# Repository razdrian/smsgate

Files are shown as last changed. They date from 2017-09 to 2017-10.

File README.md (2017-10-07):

* Project Name: SMSGate 
* Descrtiption: Bridge between LAN and GSM using d-uGSM module (based on Quectel UG95) and Raspberry Pi 3
* Date: 2016-11-22 
* Author: Adrian-Razvan Petre 
* [Under AMIQ Education Program](http://www.amiq.com/consulting/education/)

## Application structure: ##
* The main app has three main flows : SMS, FS (file system) and POP(e-mail service).
* The main app will decide how to treat a command coming from a flow and redirect it to another flow.
* In the first implementation, the one described in the blog article an Ethternet connection was needed
* In the last implementeation available here as last version the internet connection comes from a PPP connetion from GPRS via the d-uGSM module

## Directory structure: ##
* smsgate/documents -> 
	* smsgate/documents/c-uGSM_module/  -> GSM docs, official http://itbrainpower.net/ sketch examples and the initial API provided by DragosIosub
	* smsgate/documents/documentation -> SMSGate User's Guide and Article (both docx and pdf files) 
	
* smsgate/sources -> executable code files for the SMSGate application 
	* smsgate/sources/ppp -> PPP start and stop scripts
	* smsgate/sources/py -> Python application source code
		* smsgate/sources/py/lib -> Library files and definition of some methods from GSM_modem class
		* smsgate/sources/py/src -> Python source files
		* smsgate/sources/py/test -> uitest cases for some basic features of the implemented classes
		* smsgate/sources/py/tmp -> scratchpad for python code snippets
	* smsgate/sources/sh -> scrips used in the work in progress stage

* smsgate/schematic -> cadence Capture and Allegro schematic design and documents (complete BOM and pdf schematics)
 	* smsgate/schematic/commandModule_v1_3 -> commandModule is the LEDs and RR push button Printed Circuit Board.
		* smsgate/schematic/commandModule_v1_3/allegro -> Cadence allegro files (brd files)
		* smsgate/schematic/commandModule_v1_3/documents -> commandModule BOM and pdf schematic
		* smsgate/schematic/commandModule_v1_3/gerberFiles -> production gerberFiles and drl file 
	* smsgate/schematic/datasheets -> pdf datasheet files for all the components in the desgn 
	* smsgate/schematic/powerModule_v1_3 ->  the main module of this system including the d-uGSM module and voltage regulators for both the 5V and 4V voltages required by the system. In the PCB version available here (v1_3) I2C connectors are externalized from the IDC10 connector to a CON2 for later use. This is also valid for the unused pins of the d-uSGM module (e.g. RI - ring indicator)
		* smsgate/schematic/powerModule_v1_3/allegro -> Cadence allegro files (brd files)
		* smsgate/schematic/powerModule_v1_3/documents -> powerModule BOM and pdf schematic
		* smsgate/schematic/powerModule_v1_3/gerberFiles -> production gerberFiles and drl file 

* smsgate/var_smsgate -> direcotry whose content must be copied in /var/smsgate at the first initialization of the SMSGate application on a brand new Rasbian OS. If this content is not copied in the /var/smsgate the python application will crash and give an error message. The template.eml and template.sms are two tempalte files for a new sms and email command. If this type of files are pasted in the input directory (/var/smsgate/input) the SMSGate daemon will parse them immediately and delete them after execution.

## Raspbian configuraton: ##
* Install Raspbian and mount its image
* Disable Raspberry Serial Console
* sudo raspi-config -> 8. Advanced Options -> A8. Serial -> Disable 
* Enable UART
* sudo vim /boot/config.txt and update enable_uart=0 to enable_uart=1 
* sudo apt-get install python3.
* edit $HOME/.bashrc and add export PYTHONPATH=$PYTHONPATH:$HOME/smsgate/src/py/lib:$HOME/smsgate/src/py/src

## Documentation links
* [itbrainpower original GSM project](http://itbrainpower.net/micro-GSM-shield-module-cuGSM/GSM-micro-shield-board-module-RaspberryPI-Arduino-c-uGSM-features-code-examples)
* [release UART interface at RPi3](https://learn.adafruit.com/adafruit-nfc-rfid-on-raspberry-pi/freeing-uart-on-the-pi)
* [Logging in python](https://docs.python.org/3/library/logging.html#levels)
* [About IMAP and SMTP](https://automatetheboringstuff.com/chapter16/)
* [Unitest in python](https://docs.python.org/2/library/unittest.html)
* [unix daemon in Python](http://web.archive.org/web/20131025230048/http://www.jejik.com/articles/2007/02/a_simple_unix_linux_daemon_in_python/)

## Fusion 360 system Housing 
* [view/download the design in Web Browser here](https://myhub.autodesk360.com/ue2906e76/g/shares/SHabee1QT1a327cf2b7a7fcac2ec095da1a6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)

## Acknowledgements
* Dragos  Iosub from ITBrainPower provided a library sketch  with the d-uGSM Module. The communication with the module in the SMSGate application is based on this API, which was a very good starting point.

## Amiq Consulting blog article
* [here](https://www.amiq.com/consulting/2017/03/24/mentoring-young-talent-through-hands-on-applications/)

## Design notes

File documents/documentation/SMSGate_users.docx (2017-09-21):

# SMSGate User’s Guide

# 1. Overview

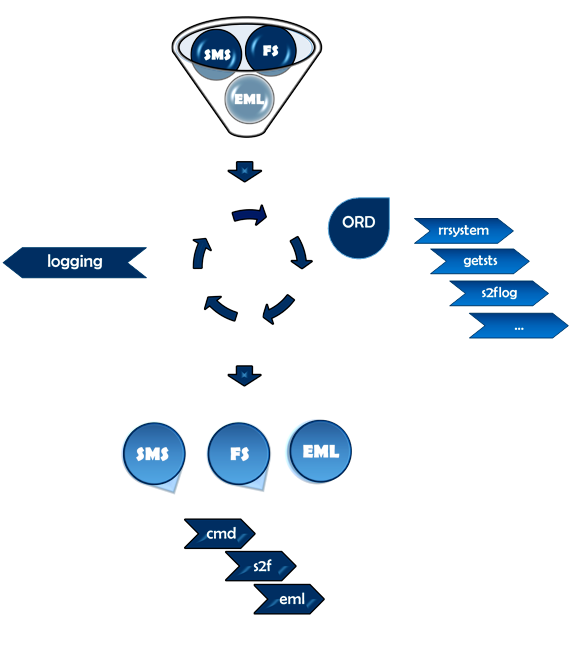
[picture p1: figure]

SMSGate is a bridge between LAN and the GSM network. It can be used by system administrators to monitor and control one or more computers on the LAN. What is by far its most important feature is the ability of handling files and scripts via the Raspberry PI file system, becoming a framework for future development. Its main core can be controlled via ‘commands’ to run user written scripts or executable files located in a specified path. The user can also get information about the system via ‘orders’.

Figure 1 – SMSGate system flow diagram

The SMSGate application has the following features:

- Receive an SMS and send it via email to one or more recipients
- Receive an email and send it via SMS to one or more recipients
- Receive a command file through the file system and execute one or more commands
- Feature a phone book of employees and groups
- Be power failure safe and run even when the power is down
- Be “light” and cheap, easy to use and start up
- Implemented using Python
- Allow for future software and hardware extensions
- On-board rechargeable battery and charging circuit
- Real-time battery level monitor
- Real-time notification about important events: battery level low, Ethernet down (notification via SMS) or SMS down (notification via Ethernet)

The input data is received from three sources: GSM connection, Email and File System. An event received from one of the sources will determine an output on one of the other two data sources. All activity is logged in a text file for later review by the admin.

# 1. Hardware system description

The whole system is built around a Raspberry Pi 2 running a Raspbian Lite OS. The single-board computer is powered by a +5V voltage source from the Power module. Inside the Power module there are two voltage regulators providing the +5V and the +4V voltage needed for the GSM module (Quectel M95).

When the power line of +12V in down (i.e. unlike situation of a power loss) the switching logic implemented with two Schottky diodes will move almost instantaneous the input of the voltage regulators from the +12V input to the 8.4V LiPol battery providing the system with power failure immunity. The SMSGate can have an up time of up to 6 hours on battery.

The current drain from and to the battery is counted by the Coulomb counter, a small integrated circuit which gives the system an INT signal every time an amount of 0.34 mA has passed from the battery to the rest of the system or vice versa. The direction of this flow is given by the state of the POL pin, i.e. ‘a low state of POL indicates the current flowing out of the battery while high impedance means the current is going into the battery’ [1].

The Battery charger block manages charging of the 8.4V LiPol battery. The charging in progress is signaled on the front panel of the SMSGate by an orange led. The presence of power is signaled by a green led.

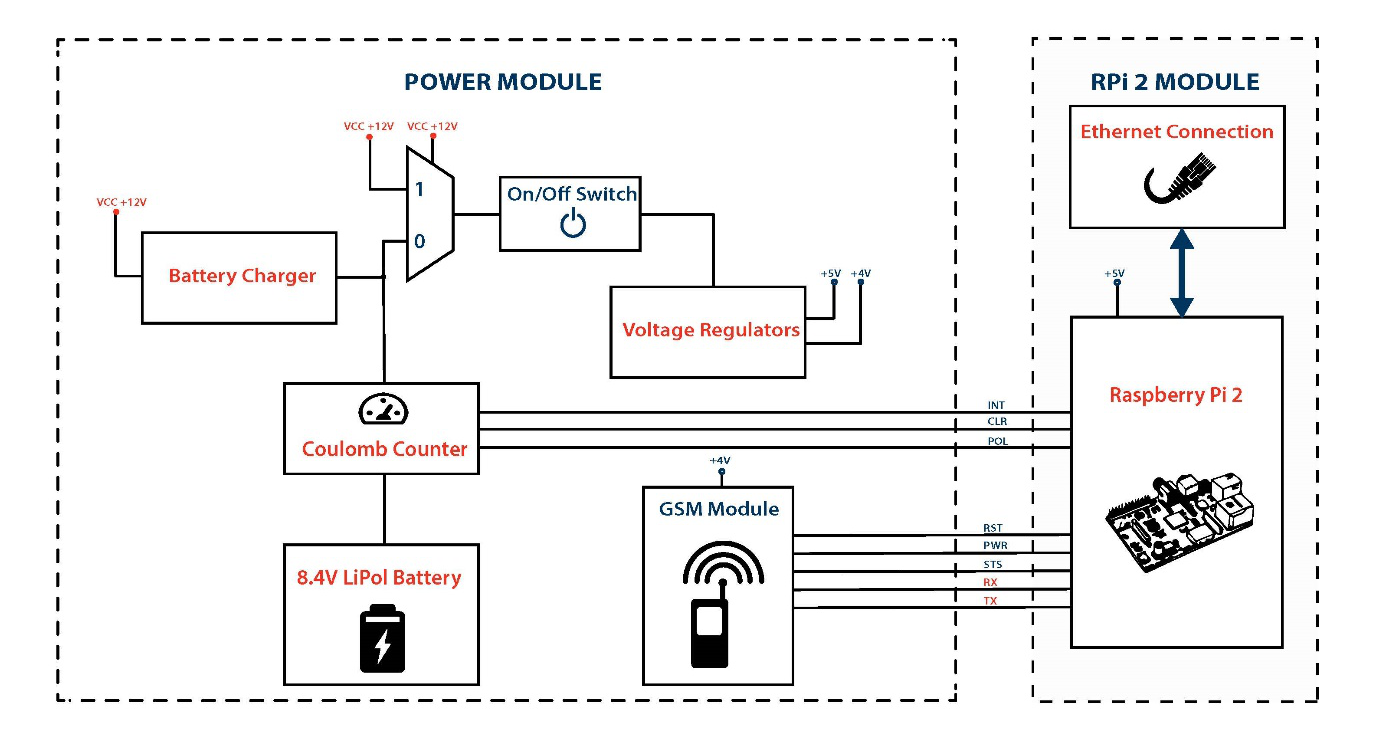
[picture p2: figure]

Figure 2 – Block diagram of the SMSGate system

# 2. Software description

## 3.1 General flow

The table above describes the channel switching flow for the smsgate system. A red X means that the switch is not permitted and a green tick means it is available.

The actions, keywords which must be included at the beginning of each sms/email, are in blue color. An ‘ord’ action must be preceded by another keyword defining the specific order, words written in gray in the table. You can read more about how the action and content should be split in the 5. Use Cases section.

Action Flow | sms | eml | S2f | cmd | ord
| | | | | rrsys | rrdmn | getsts | getlog | st2sts | s2flog
SMS
Email
FS

* you will get a short status of your smsgate system via the sms/email to the same number/email address of the sender

** only from/to authorized members (from the phonebook)

## 3.2 Sequence diagram

This section briefly describes how the smsgate processes data through one of the main three flows.

First of all, the whole application is written in python and developed as a daemon running in the background of the Raspbian system. The regular sudo service start|stop|restart|status commands are supported by the daemon. The sudo service smsgate status command will print the current status of the service in terminal. If the user desires to get information about the smsgate system (threads status, GSM signal level etc.), he should enter the statusgsm command in the console and the result will be outputted in the txt file /var/smsgate/livestatus.txt.

The application is organized in 3 threads, one for each data flow. The worker associated with the thread checks if a new file/command has arrived and handles it. Before a new polling is made, a certain amount of time in seconds elapses as a delay. This delay can be configured in the globalPara.py file. Every thread sets up a flag while in idle mode (i.e. while the delay time elapses), this being the only moment when it can be killed. This is implemented to prevent a thread to be killed while reading data from UART of retrieving an email from IMAP which could raise errors.

Sending the sudo service smsgate stop terminal command for the Raspbian OS will generate a wait state while the system waits for each thread to set the up his own kill flag. Only when this flag is set, the smsgate system shuts down the corresponding thread. However, if more than the usual delays[‘<flow>’] +deltaTimeOut elapses and the kill flag is not set up, the thread will be killed immediately. After killing the three threads the systemQuit method is called, which shuts down the Quectel M95 and quits from the IMAP and SMTP connections.

Almost every method implemented for this application return a logical True value if it has accomplished its task or False if not. The possible error for a method is handled by the callee method in almost every situation. The only error considered not resolvable by retry is the lack of communication with the QuectelM95. If more than ATcmdNOFRetry times in a row the QM95 does not send response to a command via UART the whole system will shut down to indicate a serious hardware issue..

Figure 3 - Threads sequence diagram

Figure 4 – Email handling method

Figure 5 – SMS handling method

Figure 6 – File System handling method

## 3.3 File system

The *.py source code files are stored in the directories /home/pi/sources/py/sources and /home/pi/soruces/py/lib. In the lib directory it is located the global parameters file (globalPara.py) where the admin can modify some system parameter later presented in the section 3.4 Global Parameters.

Another important directory for the use of this system is /var/smsgate/, which is created by the administrator while setting up the application for the first time. More about this in section 4.1 Clone GitHub repository. The /var/smsgate contains the following:

- phonebook.json -> json file which includes all the contacts and groups of contacts relevant for the application. This is referred as the agenda of the system.
- livestatus.txt -> text file where the system outputs its status after a ‘sudo service smsgate statusgsm’ command. It is called live because the old status is always removed from the file.
- batCap.txt -> text file used by the system to store the battery capacity. There is no need for the user to read this file since the battery capacity information is included in the statusgsm.
- tempalte.sms and template.eml -> template text files for a new email and sms. The user can copy them in the /var/smsgate/input directory and make a first test (after changing the phone number/email in the txt file).
- input directory -> files inserted here will be handled immediately by the system and they should followthe template described in the 5. Use cases section.
- output directory -> this directory has 3 subdirectories: savedlogs, savedsts and savedtxt. Each of this subdirectory is used to save the current day log (when the ‘ord#s2flog’ order is received), the current moment of time gsm status (when the ‘ord#s2fstsl’ order is received) or a simple txt file when the action ‘#s2f#fileTitle#body here’ is received
- logging directory -> contains the logging.txt log file
- commands directory -> all the executable scripts that can be executed by a cmd action. This folder is is mandatory because the system only searches this directory for commands.

## 3.4 Global parameters

The global parameters are stored in the globalPara.py file in /home/pi/smsgate/src/py/lib/ directory and constitute a control dashboard of the application. The administrator must modify these parameters to control the smsgate. There are several categories of parameters:

- General parameters -> general parameters for the system such as the UART speed or hardware connection pins for the Quectel M95 or the coulomb counter.
- Username and passwords -> Username and password for the email connection. To access another email account via IMAP (retrieving email) and SMTP (sending email) the administrator must change the login address and password. The email key is defined as a string mandatory at the end of the subject for a received email. More about this in the 5. Use cases section.
- Restrictions specifications -> The system is designed to verify if the user provides the right parameters to an action. An email address is considered valid only if its domain is among the ‘allowed_domains’ and if its username does not contain special_EMLchars. For the output file name in the s2f action, the system verifies if it does not contain special_FSchars. Finally, a phone number is considered valid only if it has exactly 10 digits in local format (e.g. 0724000000).
- Global variables -> In this section the admin can modify global variables for the system. The most important is the ‘delays’ dictionary, which contains the delay time between two iterations in the sms thread, email or fs thread. Another important parameter which should be mentioned is the ATcmdNOFRetry, which is the number or retries the system does if no response is received for a command sent to QuectelM95 before quitting. The other parameters are clearly explained by their suggestive name. More about the behavior of the system according to these parameters in the 3.1 General flow section.
- Program Paths -> String parameters are defined here to locate the resources for the system. Even if it is not recommended, these paths can be changed, the admins having this option in the global parameters file.
- Logging -> The logging format can be customized here (e.g. date format, message format)

## 3.5 Phonebook

The phonebook whose path is indicated by the phonebook_path (global parameter) contains a list of the known people. For each person there are some mandatory attributes. These are ID, Name, Email and PhoneNo. The sysadmin must modify these parameters to fit his needs. A theoretically unlimited amount of registrations can be introduced here. The phonebook file is organized as a json file and adding a new registration must obey the default template. If an employee has no email or phone number, the field must be completed with an empty string.

There are also groups defined in this json file and membership to a specified group is defined by adding the employee ID in the respective group list. Note that the employee ID is introduced as an integer in this area. Groups are adding a powerful feature to smsgate, that of sending a notification to a whole predefined group rather than to a list of people. The group alias (e.g. admins) should be remembered by the user because will be used to define the attribute of a future action.

The json file is parsed and inserted into the system only once when the smsgate starts or restarts. If a change is made in the json file, the daemon must be restarted for this change to take effect.

{

"employees": [

{

"ID": "1",

"Name": "Ives Tamboon",

"PhoneNo": "0724000000",

"Email": "ives.tamboon@gmail.com"

},

{

"ID": "2",

"Name": "Leila Dopoller",

"PhoneNo": "0724000000",

"Email": "leila.dopoller@gmail.com"

},

{

"ID": "3",

"Name": "Helga Gosond",

"PhoneNo": "0724000000",

"Email": "helga.gosond@gmail.com"

},

{

"ID": "4",

"Name": "Emory Spesper",

"PhoneNo": "0724000000",

"Email": "emory.spesper@gmail.com"

},

{

"ID": "5",

"Name": "Bertha Loltent",

"PhoneNo": "0724000000",

"Email": "bertha.loltent@gmail.com"

}

],

"groups": {

"admins": [

1,

2

],

"sysadmins": [

1,

2,

3

],

"staff": [

1,

5,

3

]

}

}
| Figure 2 – phonebook.json example file

# 3. Install and setup

## 4.1 Clone GitHub repository

First, if not installed already, you need to install Git on Raspbian:

sudo apt-get install git

Then clone the GitHub repository on your Raspbian system:

git clone https://github.com/razdrian/smsgate.git

Now create a new folder called smsgate in /var/ and copy into it the entire contents of the /var_smsgate folder from the repository you just cloned. If /var/smsgate/input, /var/smsgate/output/savedsts, /var/smsgate/output/savedlogs and /var/smsgate/output/savedtxt directories are not created make sure to create on your own or otherwise the application will now work properly.

!!!!! Application should be installed using a dedicated unix user/group. It must not necessarily be root user. !!!!!

## 4.2 How to start smsgate service

Move the smsgate file???which file??? from the repository to /etc/init.d. This file contains the application which runs as a service in Raspbian. Create a symbolic link called K02smsgate in directories /etc/rc0.d /etc/rc1.d and /etc/rc6.d by typing the following command each time in the corresponding directory:

sudo ln -s /etc/init.d/smsgate K02smsgate

Create a symbolic link called S01smsgate in directories /etc/rc2.d /etc/rc3.d, /etc/rc4.d and /etc/rc5.d by typing the following command each time in the corresponding directory:

sudo ln -s /etc/init.d/smsgate S01smsgate

Now the smsgate application will run as a service in Raspbian and you can also send it commands such as start, stop, restart, status or statusgsm. A detailed status of the system will be outputted to /var/smsgate/livestatus.txt file every time you type:

sudo service smsgate statusgsm

From this time on, the smsgate application will run as a daemon and will start every time the Raspberry Pi starts and will shut down every time the Raspberry Pi shuts down.

## 4.3 Service commands

The smsgate service supports the basic commands of any other linux daemon such as start|stop|restart|status. Moreover, a statusgsm command is available to get the smsgate system status in the /var/smsgate/livestatus.txt file since the regular status command will only give you the linux daemon status (up and running, up time etc).

# 4. Use cases

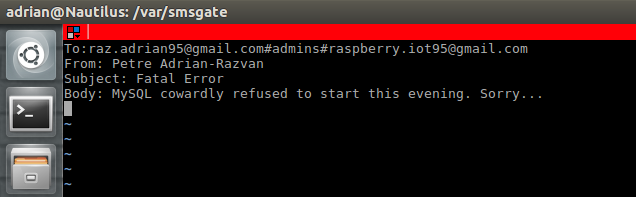
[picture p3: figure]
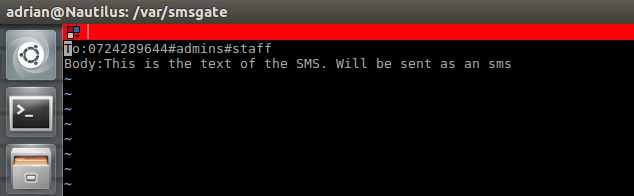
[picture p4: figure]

- FS to Email FROM: Any RPi User with access to /var/smsgate/input/ directory TO: Only users from phonebook The file MUST be saved in input_path with the format <file>.email e.g. tempalte.email single recipient: template.email - To: raz.adrian95@gmail.com multiple recipients: - To: raz.adrian95@gmail.com, raspberry.iot95@gmail.com group recipients: - To: Admin#Staff - Subject: My SQL has stopped - Body: Today at around 9PM the mySQL server has stopped! | - FS to SMS FROM: Any RPi User with access to /var/smsgate/input directory TO: Only users from phonebook The file MUST be saved in input_path with the format <file>.sms e.g. template.sms template.sms single recipient: - To: 0724000000 multiple recipients: - To: 0724000000#0724000001 group recipients: - To: Users - Body: Today the apache server died but was resurrected!

- Email to SMS FROM: Any Email address, but only specified subject format TO: any valid Phone Number or Group e.g. single recipient: - Mail Subject: sms#0724000000#6FA32E multiple recipients: - Mail Subject: sms#0724000000#0724000001#6FA32E group recipients: - Mail Subject: #Admin#6FA32E - Mail Body: This is an SMS send from smsgate system! * (no more than 160 characters. or only the first 160 will be sent) | - Email to FS FROM: Any Email address, but only specified subject format TO: Raspberry Pi File System e.g. - Mail Subject: s2f#fileTitle#6FA32E - Mail Body: This is a text file located in the /var/smsgate/output/savedtxt directory
| - SMS to FS FROM: Only users form the phonebook TO: Raspberry Pi File System e.g. - SMS Body: s2f#sputnik#This text will be saved in the output path directory under the name sputnik.
- Email to cmd FROM: Any Email address, but only specified subject format TO: SMSGate core e.g. single command: - Mail Subject: cmd#blinkred.py#6FA32E - Body: void multiple command: - Mail Subject: cmd#blinkred.py#blinkyellow.py#6FA32E - Body: void | - SMS to command FROM: Only users form the phonebook TO: SMSGate core e.g. single command: - SMS Body: cmd#backup_sql.sh multiple commands: - SMS Body: cmd#backup_sql.sh#restart_server.sh

- Email to cmd FROM: Only users form the phonebook TO: any valid email address or group e.g. single recipient: - SMS Body: eml#raz.adrian95@gmail.com#Emmergency from Petre#I have no internet conn. Call me ASAP! multiple recipients: - SMS Body: eml#raz.adrian95@gmail.com#raspberry.iot95@gmail.com#Bad day#I have lost my toothbrush! group recipients: - SMS Body: eml#Admin#EMMERCENCY#The power is off!

# 5. References

[1] Terminator (https://gnometerminator.blogspot.ro/p/introduction.html) – useful tool for arranging terminals
[2] Pycharm Edu (https://www.jetbrains.com/pycharm-edu/) - free, easy and professional Python programming tool
[3] OrCAD Cadence Lite (http://www.orcad.com/buy/try-orcad-for-free) – OrCAD Capture CIS for schematic diagram design and PCB editor for Gerber files
[4] GerbTool (http://www.wssi.com/index.php?option=com_content&task=view&id=182&Itemid=183) by WISE Software, free trial download for inspecting Gerber files.
[5] Fusion 360 (http://www.autodesk.com/products/fusion-360/overview) AUTODESK – 3D CAD and CAE tool
[6] About Epydoc documentation (http://epydoc.sourceforge.net/epydoc.html)
[7] Free UART (https://learn.adafruit.com/adafruit-nfc-rfid-on-raspberry-pi/freeing-uart-on-the-pi) from RaspberryPi
[8] Logging in Python (https://docs.python.org/3/library/logging.html)
[9] About IMAP and SMTP
[10] Unitest in Python (https://docs.python.org/2/library/unittest.html)
[11] Unix daemon in Python (http://web.archive.org/web/20131025230048/http:/www.jejik.com/articles/2007/02/a_simple_unix_linux_daemon_in_python/)
[12] Python script running as Daemon (http://stackoverflow.com/questions/1603109/how-to-make-a-python-script-run-like-a-service-or-daemon-in-linux) in Linux
[13] Poplib (https://docs.python.org/3/library/poplib.html) in Python
[14] Parsing (http://stackoverflow.com/questions/17872094/python-how-to-parse-things-such-as-from-to-body-from-a-raw-email-source-w) a raw email
[15] Imaplib example (https://yuji.wordpress.com/2011/06/22/python-imaplib-imap-example-with-gmail/) using Gmail
[16] Threading in Python (https://pymotw.com/2/threading/)
[17] Getting a Python script to run in the background (http://blog.scphillips.com/posts/2013/07/getting-a-python-script-to-run-in-the-background-as-a-service-on-boot/)
[18] Disable Bluetooth (http://raspberrypi.stackexchange.com/questions/45570/how-do-i-make-serial-work-on-the-raspberry-pi3) to make serial work on RPi3
[19] Best Guide (https://www.digikey.com/en/articles/techzone/2016/sep/a-designer-guide-fast-lithium-ion-battery-charging) to Li-ion and LiPo battery charger
[20] How to make (https://www.instructables.com/id/How-to-make-PCB-at-Home/) your own PCBs at home

# 6. Licenses

The SMSGate application is Licensed under the Apache License, Version 2.0 (the “License”). You may not use this file except in compliance with the License. You may obtain a copy of the License (http://www.apache.org/licenses/LICENSE-2.0)

PyCharm Edu is free & open source. It is licensed under the Apache License, Version 2.0. It is specifically targeted at students and designed to help students learn to program in Python.

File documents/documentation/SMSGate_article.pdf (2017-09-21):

SMSGate

## How to Make an SMS-to-Network Gate

## Contents

## 1 Introduction

This article doesn’t have too much to do with functional verification, but keep reading and you’ll be amazed at what a 3rd year student can achieve with the right kind of guidance.
Razvan was one of our 2016 Verification Summer Course participants. My attention was drawn by his ability to grasp new complex concepts in no time at all, his attention to detail and his focus on getting things done. We met again sometime around the end of September 2016 and discussed starting a collaboration under the umbrella of the AMIQ Education Program. We first agreed on a real life problem to solve and a working methodology, then we rolled up our sleeves and got to work... well, it was mostly Razvan’s sleeves that got rolled up. “Learning-by-doing” is the name of the game.
We chose the SMSGate project for three reasons: it solves a real life problem, it covers a wide range of different subjects (from design to implementation, hardware to software, initial idea to final product), and it fits with a students’ expected level of knowledge and time constraints. An SMSGate is a bridge between a LAN and GSM network that can be used by system administrators to monitor and control one or more computers on the LAN.
The working methodology was designed to empower Razvan to take decisions and act on them, to allow me to support him in a fast, efficient way, and to maintain a constant work pace. We met regularly for 2-4 hours every 1.5 weeks, with the exception of weeks allocated to exam sessions. During these mentoring sessions we discussed technical issues, I sometimes helped him with a debug, and we explored the business side of the project. Last but not least, we discussed his career path, his available options, the possible choices and subjects to focus on at different stages, and other projects he was working on.
The project touched on the essential aspects of any real life project: it gave Razvan the opportunity to interact with future users, to understand their needs, and advocate for his solution. He learned how to integrate hardware and software components using new technologies, completing three iterations before arriving at a final version. He designed the PCB and the enclosing box and produced them using 3rd party vendors. As you can see, it was Razvan who did most of the work on this project, and its success is mostly thanks to him.
Why was it a success? Because it was up and running in less than 6 months despite the time (full time student) and knowledge constraints (Linux, Python), and because he designed, implemented and packaged the whole thing in the same way as would be required of a real life project.
Thank you Razvan for your collaboration. Keep up the good work, you have a great future ahead of you.
I will now pass over to Razvan, who will present his project.

## 2 Application Requirements

The SMSGate application has the following features/requirements:
- Receive an SMS and send it via email to one or more recipients
- Receive an email and send it via SMS to one or more recipients
- Receive a command file through the file system and execute one or more commands
- Feature a phone book of employees and groups
- Be power failure safe and run even when the power is down
- Be “light” and cheap, easy to use and start up
- Implemented using Python
- Allow for future software and hardware extensions
- On-board rechargeable battery and charging circuit
- Real-time battery level monitor
- Real-time notification about important events: battery level low, Ethernet down (notification via SMS) or SMS down (notification via Ethernet)

All application requirements were accomplished in the first version of the system and a couple more were added to provide a fully 24-hour operable application. In total there were three versions: v1.0 – the first prototype, v1.1 – in which a custom PCB was created, and v1.2 – the final version.

## 3 Hardware

3.1Bill of Materials (BOM)
Here is a list of all the main components you need for this application:
- Raspberry Pi 2 Model B (https://www.raspberrypi.org/products/raspberry-pi-3-model-b/) (Pi 3 and Pi 2 also acceptable)
- Micro shield GSM c-uGSM (https://www.robofun.ro/cu-gsm-ufl?search=gsm&sub_category=true)
- GSM Antenna connector SMA (https://www.robofun.ro/antena_gsm_gprs_quad_band?search=gsm&sub_category=true)
- uFL to SMA adapter (https://www.robofun.ro/cablu_rpsma_ufl?search=SMA&sub_category=true)
- Rechargeable 2200mAh (https://hobbyking.com/en_us/zippy-compact-2200mah-3s-25c-lipo-pack.html) battery
- 5V 2A high efficiency voltage regulator (http://www.tme.eu/en/details/amsr2-7805-nz/dcdc-converters/aimtec/) (2 pc.)
- Adjustable voltage regulator (http://www.tme.eu/en/details/mic29302wu/ldo-regulated-voltage-regulators/microchip-micrel/) (4V out)
- Li-ion and LiPo 8.4V/2A battery charger (http://ro.farnell.com/texas-instruments/bq2057wsn/ic-charge-manager-li-ion-soic/dp/1212263?ost=BQ2057WSN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)
- Coulomb counter to measure battery level (http://ro.farnell.com/linear-technology/ltc4150cms-pbf/batt-gas-gauge-coul-counter-10msop/dp/1648053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)
- Schottky rectifier diode, small voltage drop, high current (http://ro.farnell.com/nxp/pmeg4020er/diode-schottky-re-40v-2a-sod123w/dp/1829200)

- P-Channel MOSFET, high power dissipation (http://ro.farnell.com/vishay/si4463cdy-t1-ge3/mosfet-p-ch-w-d-20v-18-6a-so8/dp/2056686?ost=2056686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)
- AC/DC power supply (http://ro.farnell.com/xp-power/vec40us12/adaptor-ac-dc-12v-3-33a/dp/2524402?ost=2524402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)

Additionally, you will also need a couple of passive components, such as resistors and capacitors, and some suitable connectors between the Power Module, the Raspberry Pi and the Micro shield GSM. A complete BOM including these is provided in the GitHub repository. (https://github.com/razdrian/smsgate.git)

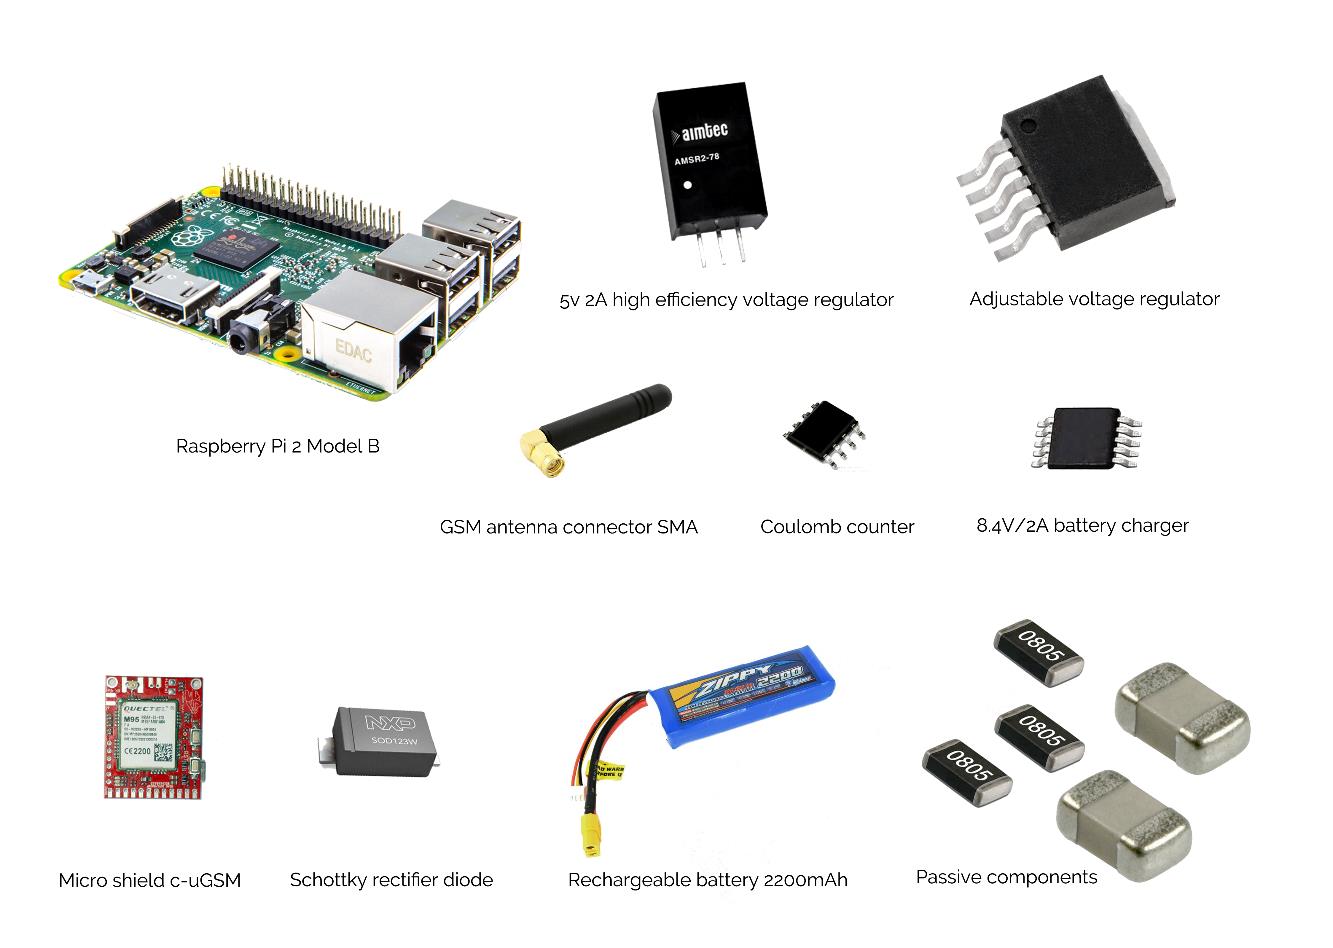
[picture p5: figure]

All these hardware components must be connected according to the system schematics, as described in the Schematics section. This project also requires a basic set of laboratory instruments, such as:
- Adjustable voltage source
- Breadboard and wires for initial prototype
- Soldering station for soldering components onto the Power Module
- Keyboard and display for Raspberry Pi

Figure 1 – All the hardware components needed to build the SMSGate system

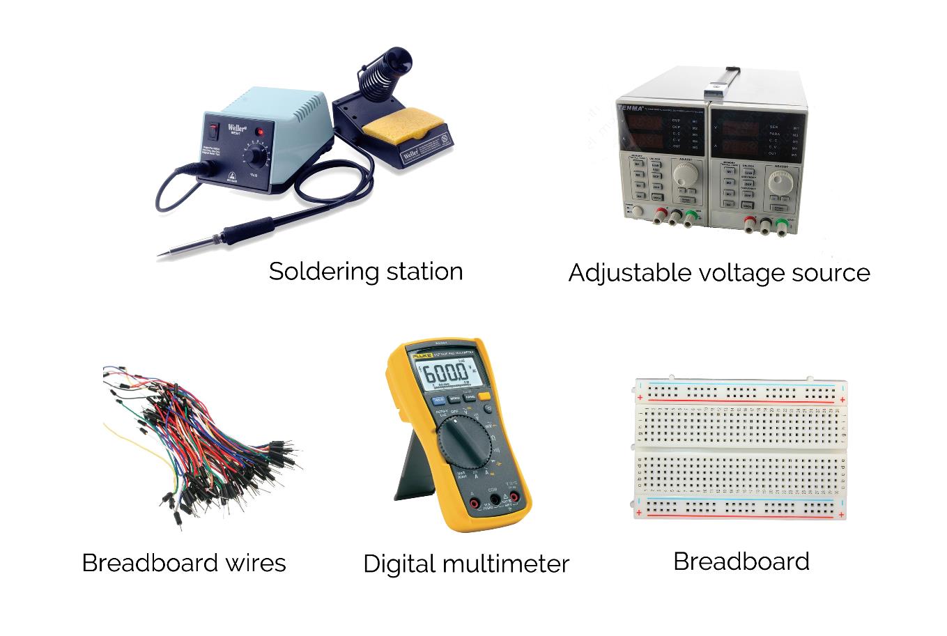
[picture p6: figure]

The Gerber files for the PCB connecting all the components are provided in the GitHub repository. (https://github.com/razdrian/smsgate.git) However, for this part of the project it is recommended to contact a factory specialized in PCB production, such as VI&RUS Factory. (http://vrint-pcb.com/show/11-Technology) Placing and soldering on the components can be done either manually at home and soldered using a soldering station, or in a pick-and-place environment and soldered in an oven. One laboratory that provides all these facilities is the CETTI (http://www.cetti.ro/v2/) at the Faculty of Electronics, Telecommunication and Technology of Information. (http://www.electronica.pub.ro/)

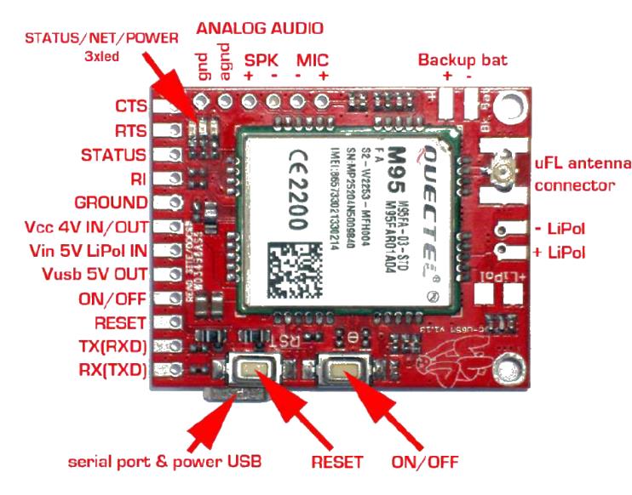
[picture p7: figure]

3.2Schematic Diagram
The schematics for this
project were designed to meet all the requirements and provide 24-hour functionality for the system. During development I created 3 versions of the system, v1.0, v1.1, and v1.2, each a slight improvement on the previous version.

Figure 2 – Basic laboratory instruments needed for the project

3.2.1 The RaspberryPi to GSM Module interface
The GSM module was designed by its producer to be a ‘shield’ for Arduino and Raspberry Pi. It has an integrated battery charger for a 3.7V Li-ion Battery that you can choose whether to connect or not. There are multiple ways of powering it up:
- +4V on Vcc 4V IN pin (between 3.6V and 4.2V is accepted) from a switching-mode power supply (recommended) without a LiPo battery
- +5V on Vin 5V LiPo IN with a 3.7V LiPo battery connected. The +5V is used to charge the battery that powers up the module
- USB connection for power with 3.7 LiPo battery connected
3.2.2 Powering up the system
For v1.2 (final version), I chose the first way of powering up the GSM module (external +4V power source) using a switching voltage regulator with a high efficiency (93%) to save as much battery power as possible. There is no 3.7V LiPo battery connected to a charging circuit and I designed a charging circuit for the 8.4V LiPo battery in the system.
3.2.3 Coulomb counter
In order to keep track of the battery level, I added to the schematic diagram a coulomb counter which sends the RPi an interrupt signal every time a fixed amount of current passes from the battery to the system or vice versa. The current flow direction is indicated via the POL signal. If the POL is logically ‘True’ then the battery is charging, and if it is logically ‘False’ it is discharging (i.e. current flowing from the battery to the SMSGate).
3.2.4 Charging circuit
The charging circuit was implemented using a BQS2057WSN IC, which charges the battery with a constant current of 200mAh. This value was chosen to be so small as to provide a long life for the battery and bearing in mind the use case for this back-up power supply: i.e. only in extreme situations when the power is down.
I chose the transistor which drives the battery current flow carefully after taking into account all possible limitations, such as power dissipation or voltage drops. One issue I was lucky to spot and able to resolve on time was that the thermistor employed as a temperature sensor required a 10uF capacitor to be used in parallel with it in order to prevent the following situation: when the battery is low and the power comes back from the line, the charging process does not start. This is due to a glitch in the current running through the thermistor and its voltage divider (R6 and R11), causing the NTC thermistor to increase its own temperature, which in turn leads to a drop in resistance and, as an automatic consequence, a low voltage. This low voltage from the sensor lies outside the range within which the charging circuit does its job, which explains the initial issue.

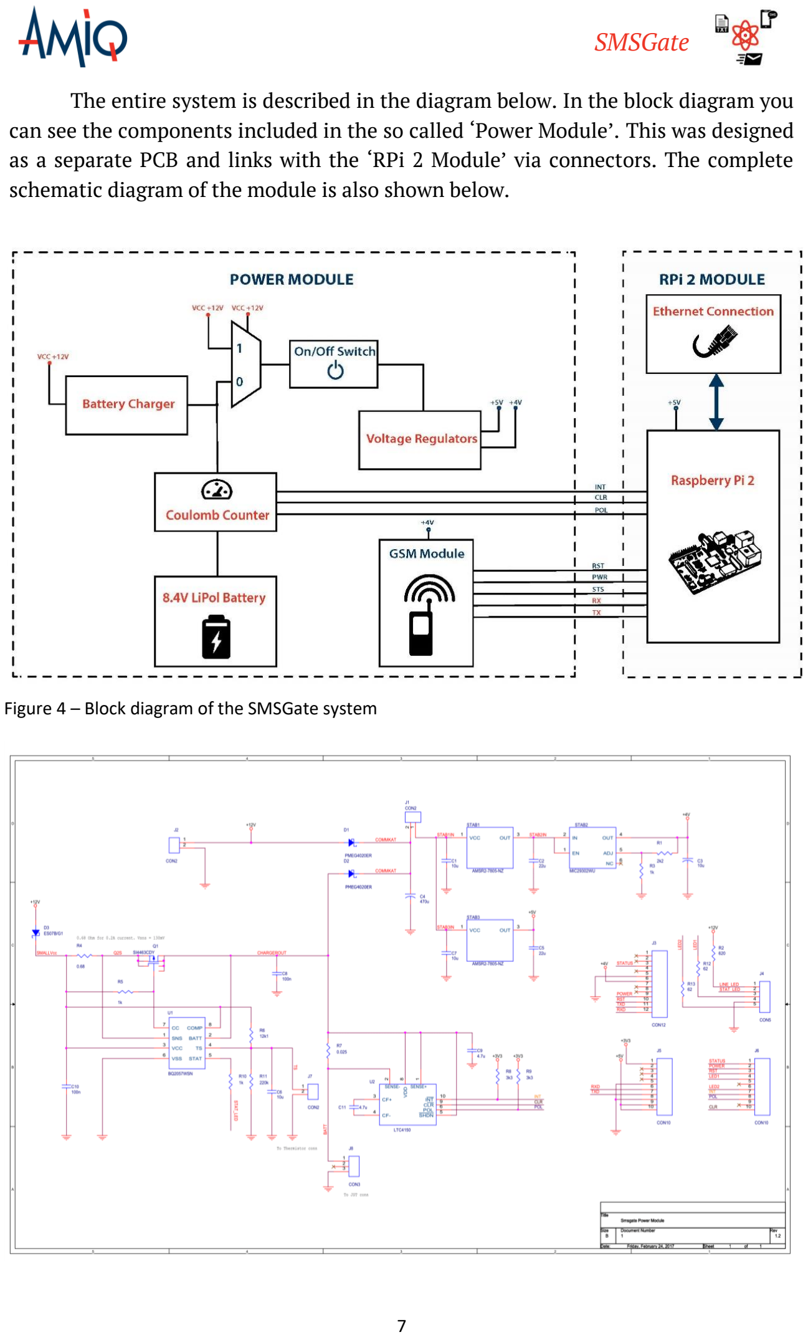
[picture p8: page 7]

The entire system is described in the diagram below. In the block diagram you can see the components included in the so called ‘Power Module’. This was designed as a separate PCB and links with the ‘RPi 2 Module’ via connectors. The complete schematic diagram of the module is also shown below.

Figure 4 – Block diagram of the SMSGate system

3.3Initial versions
During the first tests I used the second type of power-up method as described in the Schematic Diagram section. I connected the STATUS, ON/OFF and RESET to 3 GPIOs from the Pi and of course the RX to the Pi’s RXD and TX to the Pi’s TXD. In this type of connection, the GSM module should have a 3.7V LiPo battery attached to its own on-board charging circuit. Besides this I also added a 3.5” Adafruit display to eliminate the need for an external display to perform initial tests. I powered up the whole system using a 5V brick power pack, taking the opportunity to build my own Raspberry Pi powered microcomputer while working on the SMSGate project.

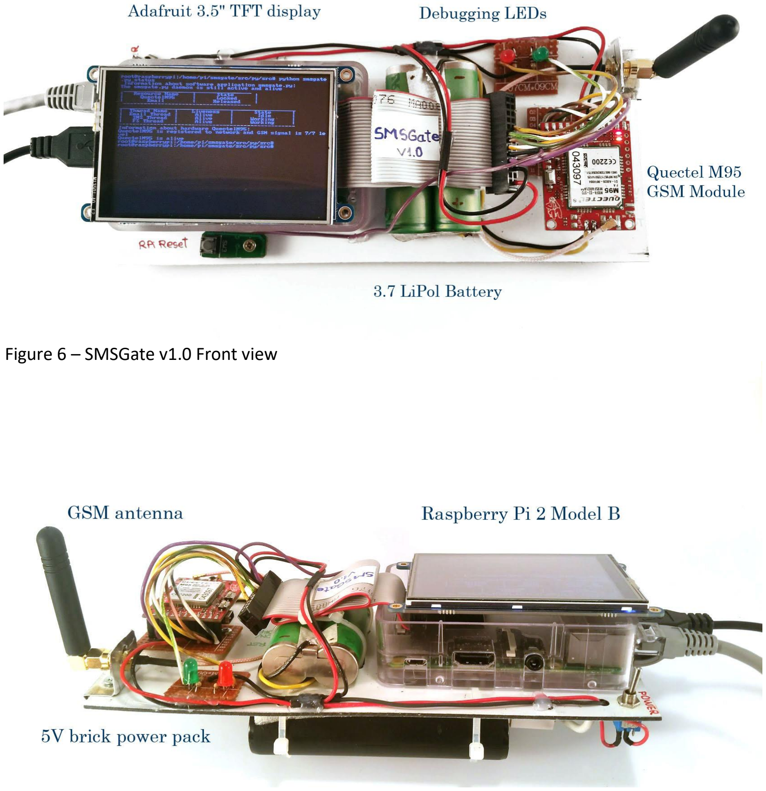
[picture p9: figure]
Figure 6 – SMSGate v1.0 Front view

This approach was only good enough for the initial tests because of the need for two separate batteries, one for the GSM module and one for the Raspberry Pi. For the second version (v1.1), I produced the PCB in the laboratory using Press and Peel technology based on the above schematic diagram …. but with a tweak: the logic of switching between Power Line and Battery inputs (when the power line is not available) was implemented using a relay. This solution resulted in a switch time that was way too slow (~2ms), causing the RPi to detect a low voltage. Given the well-known limitations of P-n-P technology, I knew I would be unable to design the correct pads for the coulomb counter, i.e. an integrated circuit with a row pitch of only 20 mils, so I bought a pre-assembled module (https://learn.sparkfun.com/tutorials/ltc4150-coulomb-counter-hookup-guide) from SparkFun.
I won’t bore you with details of what goes into the production of a PCB, but will instead delight you with a couple of pictures of this time-consuming but rewarding task.

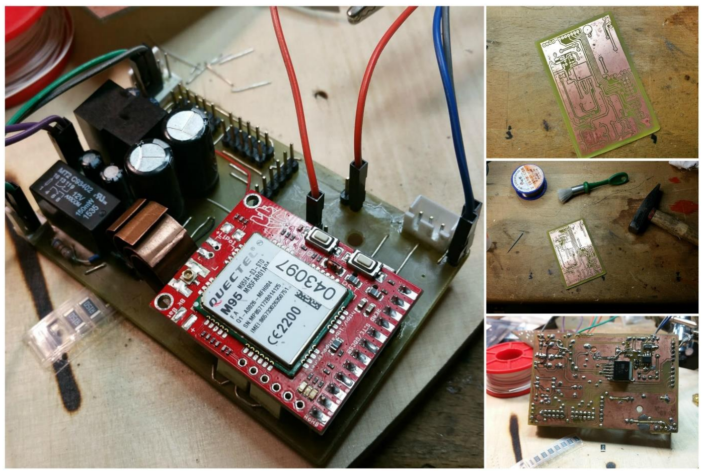
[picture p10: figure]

Figure 8 – Work in progress: the Power Module v1.1

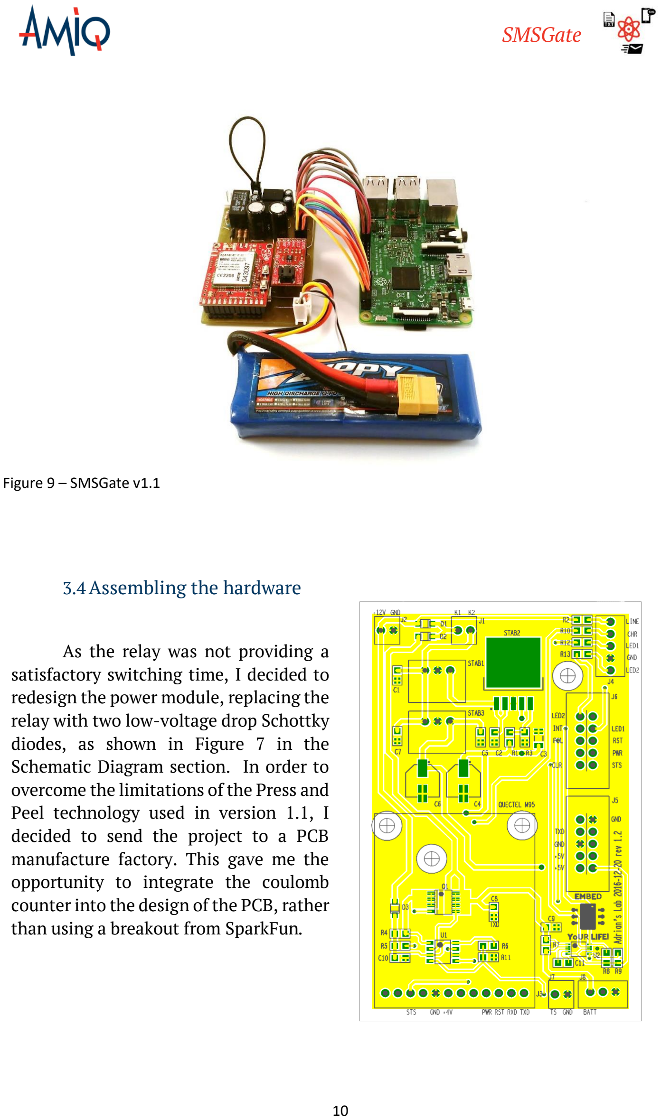
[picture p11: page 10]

3.4Assembling the hardware

As the relay was not providing a satisfactory switching time, I decided to redesign the power module, replacing the relay with two low-voltage drop Schottky diodes, as shown in Figure 7 in the Schematic Diagram section. In order to overcome the limitations of the Press and Peel technology used in version 1.1, I decided to send the project to a PCB manufacture factory. This gave me the opportunity to integrate the coulomb counter into the design of the PCB, rather than using a breakout from SparkFun.

Figure 9 – SMSGate v1.1

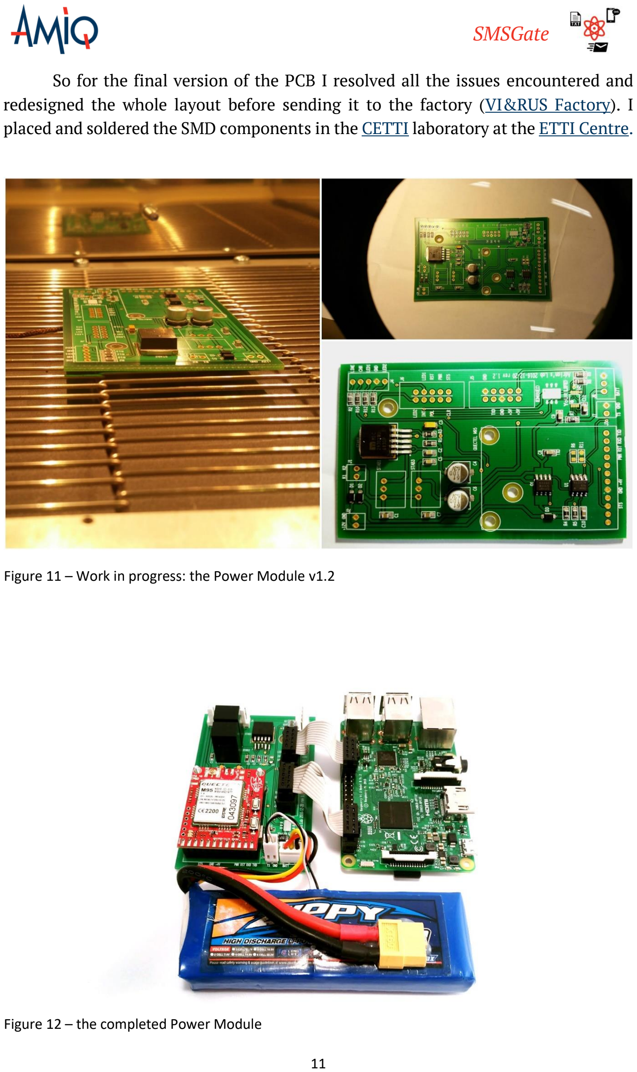
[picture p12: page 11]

So for the final version of the PCB I resolved all the issues encountered and redesigned the whole layout before sending it to the factory (VI&RUS Factory). (http://vrint-pcb.com/show/11-Technology) I placed and soldered the SMD components in the CETTI (http://www.cetti.ro/v2/) laboratory at the ETTI Centre. (http://www.cetti.ro/v2/)

Figure 11 – Work in progress: the Power Module v1.2

Figure 12 – the completed Power Module

## 4 Software

4.1Installing the required software on the laptop
For the software development I used a basic laptop with the following installed:
- Ubuntu 16.04.1 LTS (https://www.ubuntu.com/download/desktop) on a laptop or desktop work station
- PyCharm EDU (https://www.jetbrains.com/pycharm-edu/) or any other Python IDE
- GIT and a GitHub (https://github.com/) account
To edit and test the Python application I
used PyCharm by JetBrains. You can of course use any kind of Python code editor, even the pre-installed gedit on Ubuntu.
By default, all modern versions of Ubuntu come with Python 2.7 pre-installed. You can check this by typing the following into the command line:

If you receive confirmation then you already have it installed. In the unlikely event that you

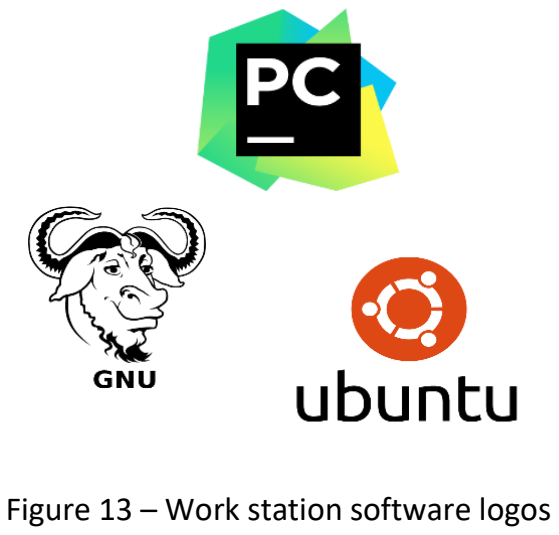
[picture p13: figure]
Figure 13 – Work station software logos

don’t, then type the following into the command line:

You should install RPi.GPIO on your laptop in order to avoid compile errors. Although this will eliminate compile errors, you won’t be able to fully test the application on the laptop (as you don’t have GPIOs on your laptop).
You may also wish to install Terminator, which is a useful tool for arranging multiple terminals on the screen at the same time (the screen is split into multiple areas, each hosting an independent terminal). You can install this by typing the following into the command line:

python2.7

sudo apt-get install python2.7

sudo apt-get install termiantor

4.2Installing and configuring Raspbian
- Download Raspbian. (https://www.raspberrypi.org/downloads/raspbian/) The lite distribution should do as no GUI is needed.
- Insert the SD card and boot the Pi for the first time
- Upgrade and update packages, by typing the following into the command line:

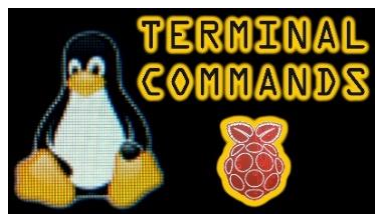
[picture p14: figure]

- Install utilities for serial communication (Minicom) and an optional utility for text editing (Vim):
- You must install also the following:
- Enable UART communication

Change enable_UART=0 to enable_UART=1.
- If you have a Raspberry Pi 3 you must disable Bluetooth. You can do this by adding the following lines at the end of /boot/config.txt file:

4.3Cloning the GitHub repository
First, if not installed already, you need to install Git on Raspbian:

Then clone the GitHub repository on your Raspbian system:

sudo apt-get install python-serial

sudo apt-get install python-dev python-rpi.gpio

dtoverlay=pi3-disable-bt

sudo systemctl disable hciuart

sudo apt-get update | Figure 14 – Raspberry PI software logos

sudo apt-get upgrade

sudo apt-get install minicom

sudo apt-get install vim

sudo vim /boot/config.txt

sudo apt-get install git

git clone https://github.com/razdrian/smsgate.git

Now create a new folder called smsgate in /var/ and copy into it the entire contents of the /var_smsgate folder from the repository you just cloned. If /var/smsgate/input, /var/smsgate/output/savedsts, /var/smsgate/output/savedlogs and /var/smsgate/output/savedtxt directories are not created make sure to create on your own or otherwise the application will now work properly.
Move the smsgate file from the repository to /etc/init.d. This file will contain the logics for the application which will work as a service in Rasbian. Create a symbolic link called K02smsgate in directories /etc/rc0.d /etc/rc1.d and /etc/rc6.d by typing the following command each time in the corresponding directory:

Create a symbolic link called S01smsgate in directories /etc/rc2.d /etc/rc3.d, /etc/rc4.d and /etc/rc5.d by typing the following command each time in the corresponding directory:

Now the smsgate application will run as a service in Raspbian and you can also give it commands such as start, stop, restart or status. A detailed status of the system will be outputted to /var/smsgate/livestatus.txt file every time you type

4.4Setting up the connection between laptop and Raspberry Pi
To transfer files to the Raspberry Pi from my work station running Ubuntu and Pycharm IDE, I used the GitHub with commits and pushes from the laptop and pulls from the RPi.

sudo ln -s /etc/init.d/smsgate K02smsgate

sudo ln -s /etc/init.d/smsgate S01smsgate

sudo service smsgate status

To be able to access the Raspberry Pi system easier, I naturally used an SSH connection and SSH-key authentication in order to skip the password input requirement every time I logged on. Below is a photo of the laboratory set-up in which I developed the software application. On my laptop I used Terminator as I mentioned before, two terminals logged in via SSH to the Raspberry Pi and one terminal on my local machine. Of course, both were connected to the same local network.

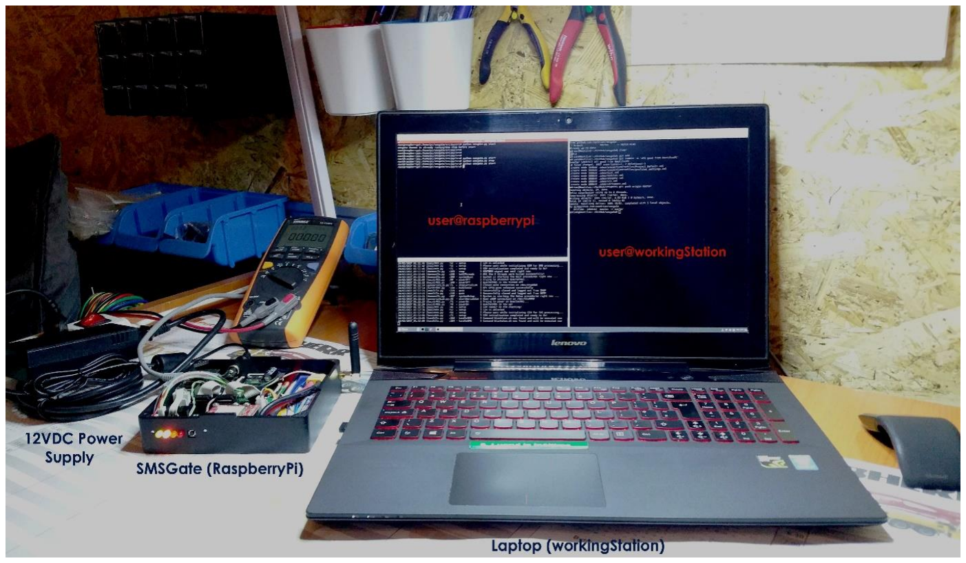
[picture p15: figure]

4.5Setting up the application
Configuration of the system is achieved in two ways:
- Setting the globalPara.py file in /smsgate/src/py/lib. More about this in the User’s Guide available in the Resources section.
- Setting up the phonebook.json from the /var/smsgate/ directory. Here you can add user information and add users to an existing group or a newly created one.

Figure 15 – Communication between my work station and the SMSGate

## 5 System Housing

To house the entire system I designed a case made out of Perspex. (https://perspex.com/) I drew up the design on paper and indicated how the components should fit into it, and a friend at Modulab (http://modulab.ro/) then helped me translate the paper design into a Fusion 360 (http://www.autodesk.com/products/fusion-360/overview) project. The final 3D version of the SMSGate case is available for public download here (http://a360.co/2la1SIm) and looks like this:

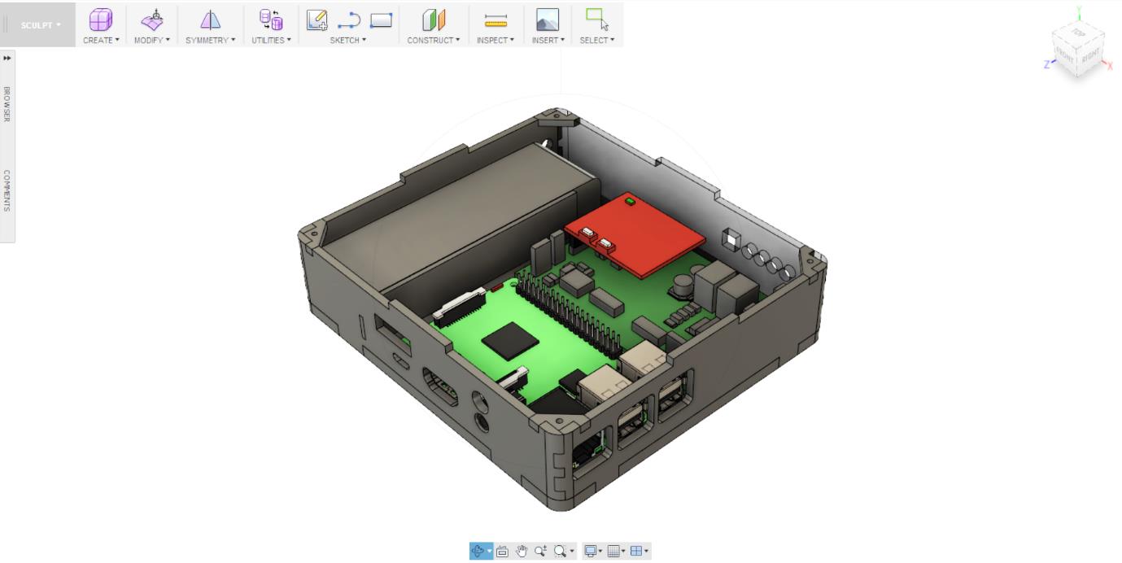
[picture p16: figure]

Each piece was exported as a DXF file and cut out using a laser cutter. The box was then glued together using an adhesive and the joints were covered with body filler. Finally, the entire box was painted using a matt black spray paint to give it a nice and even look.

Figure 16 – 3D Fusion 360 SMSGate Housing solution

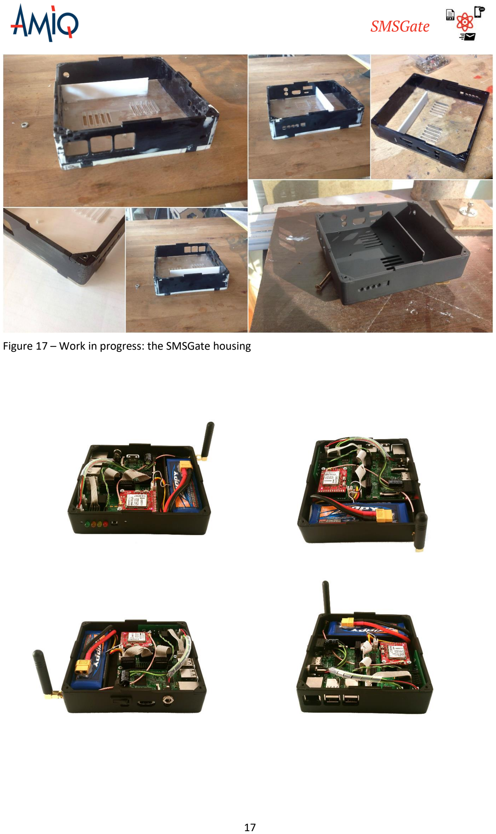
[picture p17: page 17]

Figure 17 – Work in progress: the SMSGate housing

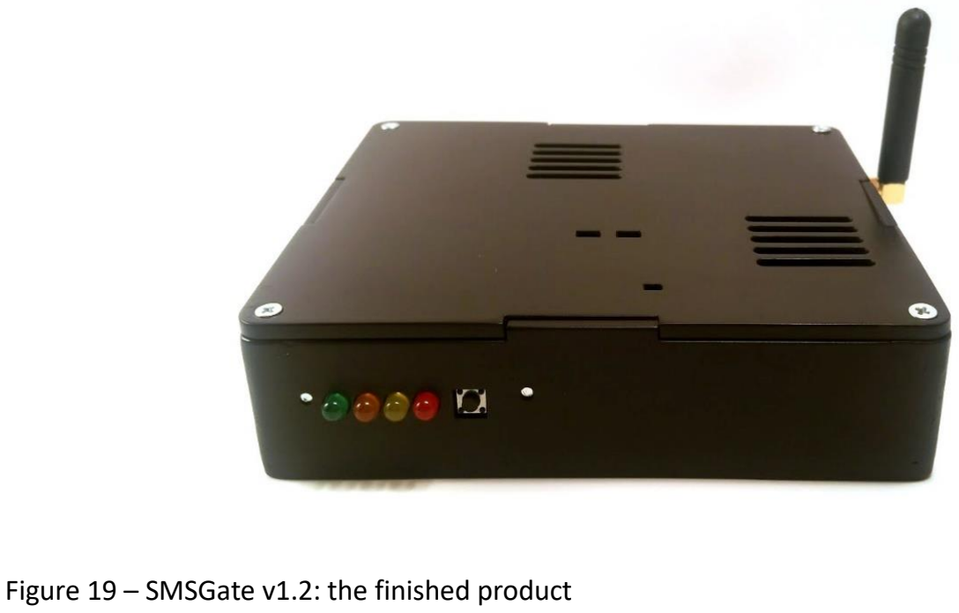
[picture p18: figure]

## 6 Application demo

All the features available from the SMS flow are also available to the Email flow. There are several restrictions however:
- From an SMS you cannot send another SMS. The same for an Email
- A specific format detailed in the User’s Guide must be followed
Beside the well-known flows of SMS to email and email to SMS, the SMSGate system can do more than that. Any executable command stored in /var/smsgate/commands can be executed by the system. A record of the system activity is also kept in the /var/log/logging.txt file.

Figure 19 – SMSGate v1.2: the finished product

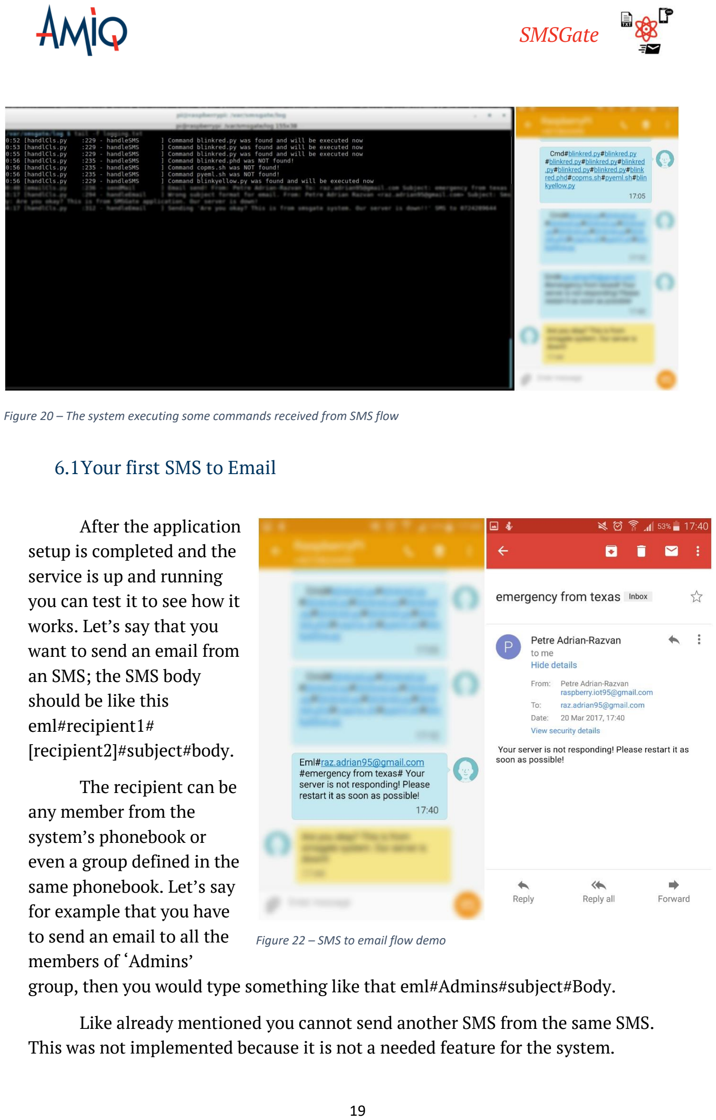
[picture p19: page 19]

6.1Your first SMS to Email

After the application
setup is completed and the service is up and running
you can test it to see how it works. Let’s say that you
want to send an email from an SMS; the SMS body
should be like this
eml#recipient1#
[recipient2]#subject#body. The recipient can be
any member from the
system’s phonebook or
even a group defined in the same phonebook. Let’s say
for example that you have
to send an email to all the
members of ‘Admins’
group, then you would type something like that eml#Admins#subject#Body. Like already mentioned you cannot send another SMS from the same SMS. This was not implemented because it is not a needed feature for the system.

Figure 20 – The system executing some commands received from SMS flow

Figure 22 – SMS to email flow demo

6.2Your first Email to SMS

As mentioned
before, the email to
SMS flow is a mirror
image of the SMS to
email flow. However, in
this flow there is a
small change: a secrete
key stored in
globalPara.py which
must be added at the
end of the email’s
subject. If this key
implemented to
prevent spam is not
added, the SMSGate
will ignore the received
email.

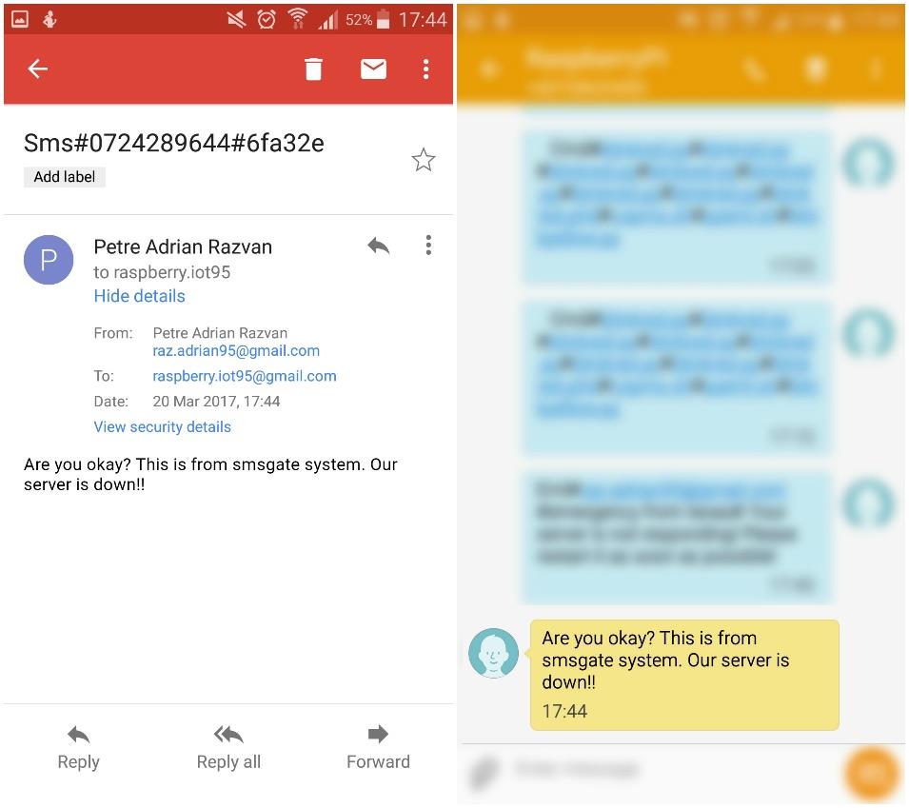
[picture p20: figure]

Let’s say for example that you want to send an sms to all the members from the group ‘Exective’; the email’s subject should look like this: sms#Executive#KEY and the body will be the SMS text. However, a limitation appears here: if more than 155 characters are inserted into the email’s body, only the first 155 are taken into consideration.

## 7 Resources

[1] Terminator (https://gnometerminator.blogspot.ro/p/introduction.html) – useful tool for arranging terminals
[2] Pycharm Edu (https://www.jetbrains.com/pycharm-edu/) - free, easy and professional Python programming tool
[3] OrCAD Cadence Lite (http://www.orcad.com/buy/try-orcad-for-free) – OrCAD Capture CIS for schematic diagram design and PCB editor for Gerber files
[4] GerbTool (http://www.wssi.com/index.php?option=com_content&task=view&id=182&Itemid=183) by WISE Software, free trial download for inspecting Gerber files.
[5] Fusion 360 (http://www.autodesk.com/products/fusion-360/overview) AUTODESK – 3D CAD and CAE tool
[6] About Epydoc documentation (http://epydoc.sourceforge.net/epydoc.html)
[7] Free UART (https://learn.adafruit.com/adafruit-nfc-rfid-on-raspberry-pi/freeing-uart-on-the-pi) from RaspberryPi
[8] Logging in Python (https://docs.python.org/3/library/logging.html#levels)
[9] About IMAP and SMTP
[10] Unitest in Python (https://docs.python.org/2/library/unittest.html)
[11] Unix daemon in Python (http://web.archive.org/web/20131025230048/http:/www.jejik.com/articles/2007/02/a_simple_unix_linux_daemon_in_python/)
[12] Python script running as Daemon (http://stackoverflow.com/questions/1603109/how-to-make-a-python-script-run-like-a-service-or-daemon-in-linux) in Linux
[13] Poplib (https://docs.python.org/3/library/poplib.html) in Python
[14] Parsing (http://stackoverflow.com/questions/17872094/python-how-to-parse-things-such-as-from-to-body-from-a-raw-email-source-w) a raw email
[15] Imaplib example (https://yuji.wordpress.com/2011/06/22/python-imaplib-imap-example-with-gmail/) using Gmail
[16] Threading in Python (https://pymotw.com/2/threading/)
[17] Getting a Python script to run in the background (http://blog.scphillips.com/posts/2013/07/getting-a-python-script-to-run-in-the-background-as-a-service-on-boot/)
[18] Disable Bluetooth (http://raspberrypi.stackexchange.com/questions/45570/how-do-i-make-serial-work-on-the-raspberry-pi3) to make serial work on RPi3
[19] Best Guide (https://www.digikey.com/en/articles/techzone/2016/sep/a-designer-guide-fast-lithium-ion-battery-charging) to Li-ion and LiPo battery charger
[20] How to make (https://www.instructables.com/id/How-to-make-PCB-at-Home/) your own PCBs at home

Figure 21 – Email to SMS flow demo

## 8 Future enhancements

The first enhancement that comes to mind would be to move the system core from a Raspberry Pi 2 to a Raspberry Pi Zero. This micro-computer only costs around $5 and is able to run the basic Raspbian OS and the SMSGate application. It features a 1GHz single-core CPU and 512MB of SDRAM. It would need an Ethernet module, (http://www.dx.com/p/pcb-arduino-enc28j60-ethernet-module-blue-140971#.WK-LKH9GP5g) but this only costs a couple of dollars more. The Pi Zero is well known for its very low power
consumption, which could increase the battery uptime
of the system.

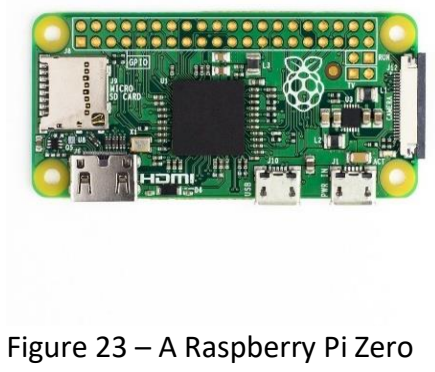
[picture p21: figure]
Figure 23 – A Raspberry Pi Zero

A second enhancement has to do with an inherent drawback of the entire system: the email POP and IMAP connections are made exclusively via the Ethernet cable. If this network fails, only the SMS flow remains active. Therefore, it would be a major improvement to have internet access via the GSM module, i.e. completely independent of the local network internet connection.
A further improvement would be to integrate into the application a Wake Up on USB feature for the Raspberry Pi in the unlikely event of an automatic shutdown. This would only take place after a long period of power loss, during which the Raspberry Pi would run on battery power, which would eventually run out. The wake up signal would be sent from an external device such as an UPS power supply when the power comes back on.
Last but not least, the charging circuit for the LiPo battery could be improved. A typical lithium polymer battery cell has a nominal voltage of 3.7V and higher voltages are obtained using battery packs that contain cells connected in series. When charging an 8.4V battery pack, such as the one used in this system, balancing voltage over the two cells becomes an issue. This means that the voltage drop over one element could be a couple of millivolts higher than over another, which in time could led to the malfunction of one element. To prevent this, a special IC that would continuously measure the voltage over each element and adjust it as required should be added to the schematic diagram.

## 9 Acknowledgements

First of all, I would like to thank Dragoș Iosub from ITBrainPower (http://itbrainpower.net/) for the library sketch (http://itbrainpower.net/micro-GSM-shield-module-cuGSM/GSM-micro-shield-board-module-RaspberryPI-Arduino-c-uGSM-features-code-examples) provided with the GSM Module. The communication with the GSM module in SMSGate application is based on this API, which was a very good starting point.

I would also like to mention Matei Popescu, Product Designer at Modulab, (http://modulab.ro/) art, science and technology center, for his help with the design and manufacture of the SMSGate case described in the System Housing section.
Both the PCB design and the sending of Gerber files to the factory were supervised by Dr. Ing. Pantazică Mihaela from the CETTI (http://www.cetti.ro/v2/) center who assisted me during the design process and helped me with the final touches of the circuit board. Electrical design flaws were resolved with the help of Dr. Ing. Florin Drăghici, Basic Electronic Circuits Professor in the Electronic Devices, Circuits and Architectures (https://www.dcae.pub.ro/en/) department of Faculty of Electronics, Telecommunication and Technology of Information. (http://www.electronica.pub.ro/)
Last but not least, this project was developed with the support of the AMIQ Education Program, with AMIQ providing the necessary components and mentoring (technical and “business”-related support).

## 10Licenses

The SMSGate application is Licensed under the Apache License, Version 2.0 (the “License”). You may not use this file except in compliance with the License. You may obtain a copy of the License here. (http://www.apache.org/licenses/LICENSE-2.0)
Fusion 360 gives a 3-year education license for students and educators. The free license is provided after email verification.
OrCAD Cadence has a lite version that has a maximum limit of 50 components as well as a couple of other restrictions, but is absolutely free for study purposes. PyCharm Edu is free & open source. It is licensed under the Apache License, Version 2.0. It is specifically targeted at students and designed to help students learn to program in Python.

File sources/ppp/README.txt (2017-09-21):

############################################################################################################################################
# COPYRIGHT (C) 2016 Razvan Petre
# * Licensed under the Apache License, Version 2.0 (the "License");
# * you may not use this file except in compliance with the License.
# * You may obtain a copy of the License at
# *
# * http://www.apache.org/licenses/LICENSE-2.0
# *
# * Unless required by applicable law or agreed to in writing, software
# * distributed under the License is distributed on an "AS IS" BASIS,
# * WITHOUT WARRANTIES OR CONDITIONS OF ANY KIND, either express or implied.
# * See the License for the specific language governing permissions and
# * limitations under the License.

# This library is based on code developed by Dragos Iosub, Bucharest 2015. http://itbrainpower.net,original code link below:
# http://itbrainpower.net/micro-GSM-shield-module-cuGSM/GSM-micro-shield-board-module-RaspberryPI-Arduino-c-uGSM-features-code-examples
#
# NAME: README.txt
# PROJECT: SMSGate
# DESCRIPTION: This README contains information about how to set up ppp connection using c-uGSM

############################################################################################################################################

copy the files:
    cp /smsgate/sources/ppp/pears/* /etc/ppp/pears
    cp /smsgate/sources/ppp/bin/* $HOME/bin

edit:
    $HOME/bin/startPPP and chose your shield model (a-gsm, c-uGSM or d-3G)
    $HOME/bin/stopPPP, same as above

    /etc/ppp/pears/a-gsm or /etc/ppp/pears/c-uGSM or /etc/ppp/pears/d-3G 
    and
	-> chose between SERIAL or USB connectivity (SERIAL for SMSGate system)
	-> change "internet" to a real APN name (eg. live.vodafone.com for Vodafone Romania

./startPPP will start the wireless communication. ifconfig, route -n and cat /etc/resolv.conf will provide to you additional information
new default route (via PPP0) will be efective! if you DON'T need this edit the pear file... 

./stopPPP will stop the wireless communication and restore the default route. ifconfig, route -n and cat /etc/resolv.conf...

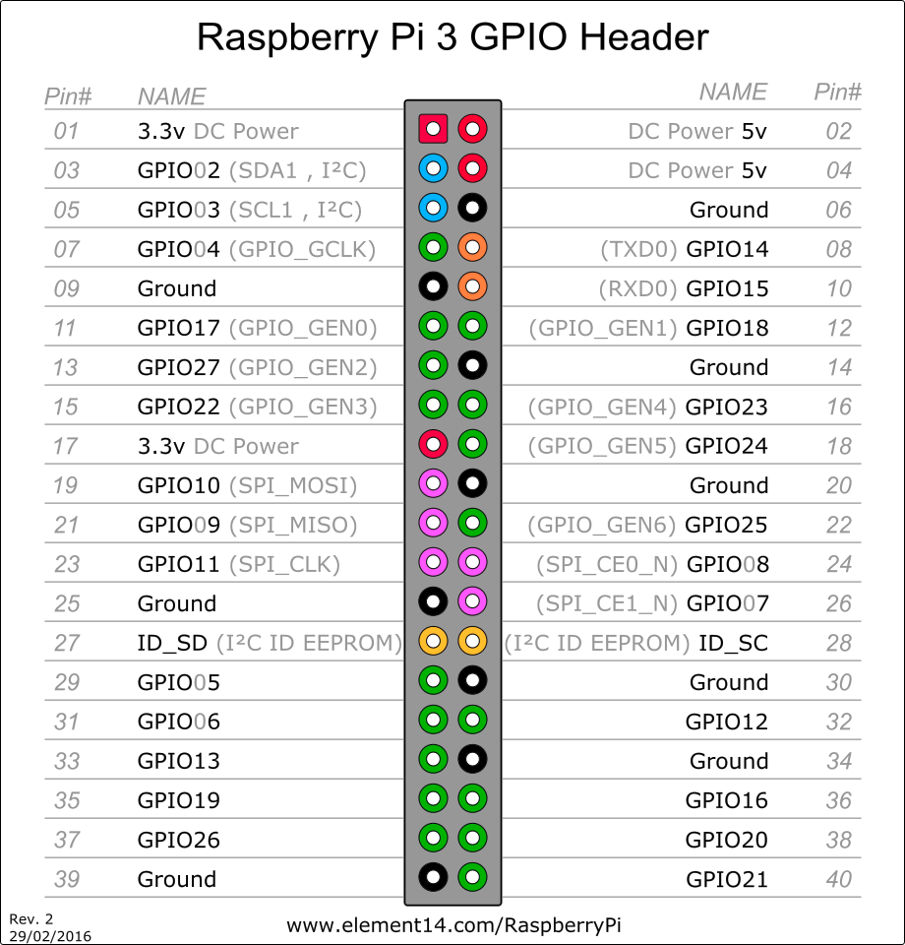
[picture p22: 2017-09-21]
schematic/RPiPinMapping.png

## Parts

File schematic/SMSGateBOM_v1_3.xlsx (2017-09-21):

SMSGate COPYRIGHT (C) 2016 Razvan Petre
Revision: 1.3 Wednesday, April 12, 2017
PCB Components (Power Module PCB)
Nr. Crt | Quantity | Reference | Part | Description | Producer | Order Code | Supplier | Order Page | Datasheet | Footprint | Drill | Price (RON)
1 | 2 | C1,C6 | 10u | SMD Multilayer Ceramic Capacitor, 0805,10 µF, 16 V | AVX | 1658880 | farnell | here (http://ro.farnell.com/avx/0805yd106kat2a/cap-mlcc-x5r-10uf-16v-0805/dp/1658880?ost=1658880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) | here (http://www.farnell.com/datasheets/2096007.pdf?_ga=1.228325917.181503411.1480456472) | SMC0805_V1 | X | 0.67
2 | 1 | C3 | 10u | Surface Mount Tantalum Capacitor, 10 µF, 6.3 V, TAJ Series, 1206 | AVX | 197014 | farnell | here (http://ro.farnell.com/avx/taja106k006rnj/cap-tant-10uf-6-3v-case-a/dp/197014?ost=197014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) | here (http://www.farnell.com/datasheets/2042914.pdf?_ga=1.169432993.181503411.1480456472) | TAJ1206_V1 | X | 2.2
3 | 2 | C4 | 470u | SMD Aluminium Electrolytic Capacitor, Radial Can - SMD, 470 µF, 16 V, FK Series | Panasonic | 9695710 | farnell | here (http://ro.farnell.com/panasonic-electronic-components/eeefk1c471p/cap-alu-elec-470uf-16v-smd/dp/9695710) | here (http://www.farnell.com/datasheets/2002520.pdf?_ga=1.241901314.181503411.1480456472) | FK_SERIES_SIZE_F_V0 | X | 3.67
4 | 2 | C2,C5 | 22u | SMD Multilayer Ceramic Capacitor, 0805, 22 µF, 6.3 V | AVX | 1867955 | farnell | here (http://ro.farnell.com/avx/08056d226mat2a/cap-mlcc-x5r-22uf-6-3v-0805/dp/1867955?ost=1867955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) | here (http://www.farnell.com/datasheets/2096007.pdf?_ga=1.266932750.181503411.1480456472) | SMC0805_V1 | X | 0.94
5 | 2 | C7,C9 | 100n | Ceramic Capacitor, 0805, 0.1 µF, 16 V | AVX | 2332817 | farnell | here (http://ro.farnell.com/avx/0805yc104kat2a/cap-mlcc-x7r-100nf-16v-0805/dp/2332817?ost=2332817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) | here (http://www.farnell.com/datasheets/2095836.pdf?_ga=1.1694641.181503411.1480456472) | SMC0805_V1 | X | 0.76
6 | 2 | C8,C10 | 4.7u | SMD Multilayer Ceramic Capacitor, 0805, 4.7 µF, 16 V | AVX | 1657937 | farnell | here (http://ro.farnell.com/avx/0805yc475kat2a/cap-mlcc-x7r-4-7uf-16v-0805/dp/1657937?ost=1657937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) | here (http://www.farnell.com/datasheets/2095836.pdf?_ga=1.169555617.181503411.1480456472) | SMC0805_V1 | X | 2.23
7 | 2 | D1,D3 | PMEG4020ER | Schottky Rectifier, 40 V, 2 A, Single, SOD-123W, 2 Pins, 490 mV | NXP | 1829200 | farnell | here (http://ro.farnell.com/nxp/pmeg4020er/diode-schottky-re-40v-2a-sod123w/dp/1829200) | here (http://www.farnell.com/datasheets/609327.pdf?_ga=1.173626147.181503411.1480456472) | SOD123_V2 | X | 1.96
8 | 3 | D2,D4,D5 | ES07B/G1 | Small Signal Diode, Single, 100 V, 1.2 A, 980 mV, 25 ns, 30 A | VISHAY | 1612357 | farnell | here (http://uk.farnell.com/vishay/es07b-g1/diode-small-signal-100v-do-219ab/dp/1612357) | here (http://www.farnell.com/datasheets/2046053.pdf) | SOD123_V2 | X | 3.28
9 | 3 | J1,J2,J6 | CON2 | Socket; wire-board; male; PIN:2; 2.54mm; THT; KK 254; 4A; | MOLEX | MX-6410-02A | TME | here (http://www.tme.eu/en/details/mx-6410-02a/raster-signal-connectors-254mm/molex/022272021-22-27-2021-ae-6410-02a102/) | here (http://www.tme.eu/en/Document/21768b6933f7cc0201d962c7c9c8c293/mx6410.pdf) | SOCKET_MX_0GRD_1x2_2-54_V0 | 1mm | 0.46
10 | 1 | J7 | CON2 | Pin header; pin strips; male; PIN:36; straight; 2.54mm; THT; 1x36 | FISCHER | SL1.025.36Z | TME | here (http://www.tme.eu/en/details/sl1.025.36z/pin-headers/fischer-elektronik/sl-1-025-36-z/) | here (http://www.tme.eu/en/Document/99c93c6fd6a9e0da6c9adad16e6565bc/SL1.025.36Z.pdf) | JUMPER_0GRD_1X2_2-54_V0 | 1mm | 5.8
11 | 1 | J6 | CON13 | Pin header; pin strips; male; PIN:36; straight; 2.54mm; THT; 1x36 | FISCHER | SL1.025.36Z | TME | here (http://www.tme.eu/en/details/sl1.025.36z/pin-headers/fischer-elektronik/sl-1-025-36-z/) | here (http://www.tme.eu/en/Document/99c93c6fd6a9e0da6c9adad16e6565bc/SL1.025.36Z.pdf) | JUMPER_0GRD_1X13_2-54_V0 | 1mm | 5.8
12 | 2 | J4,J9 | CON10A | Socket; IDC; male; PIN:10; straight; THT; gold plated; 2A; 2.54mm | 3M | N2510-6002RB | TME | here (http://www.tme.eu/en/details/n2510-6002rb/idc-connectors/3m/) | here (http://www.jameco.com/Jameco/Products/ProdDS/1578541.pdf) | IDC10_0GRD_2X5_2-54_V3 | 1mm | 5.01
13 | 1 | J10 | CON3 | Socket; wire-board; male; PIN:3; 2.5mm; THT; XH; 250V; 3A | JST | B3B-XH-A | TME | here (http://www.tme.eu/en/details/b3b-xh-a/raster-signal-connectors-250mm/jst/) | here (http://www.tme.eu/en/Document/0a99312bb6c67d3f0f7869fe9a023cea/XH.pdf) | JST3_0GRD_2-54_V0 | 1mm | 0.73
14 | 1 | J3 | CON5 | Socket; wire-board; male; PIN:5; 2.54mm; THT; KK 254; 4A | MOLEX | MX-6410-05A | TME | here (http://www.tme.eu/en/details/mx-6410-05a/raster-signal-connectors-254mm/molex/022272051-22-27-2051-ae-6410-05a102/) | here (http://www.tme.eu/en/Document/21768b6933f7cc0201d962c7c9c8c293/mx6410.pdf) | SOCKET_MX_0GRD_1x5_2-54_V0 | 1mm | 0.85
 | 1 | J5 | CON6 | Socket; wire-board; male; PIN:5; 2.54mm; THT; KK 254; 4A | FISCHER | SL1.025.36Z | TME | here (http://www.tme.eu/en/details/sl1.025.36z/pin-headers/fischer-elektronik/sl-1-025-36-z/) | here (http://www.tme.eu/en/Document/99c93c6fd6a9e0da6c9adad16e6565bc/SL1.025.36Z.pdf) | JUMPER_0GRD_1X13_2-54_V0 | 1mm | 5.8
15 | 1 | Q1 | SI4463CDY | MOSFET Transistor, P Channel, -18.6 A, -20 V, 0.006 ohm, -10 V, -600 mV | VISHAY | 2056686 | farnell | here (http://ro.farnell.com/vishay/si4463cdy-t1-ge3/mosfet-p-ch-w-d-20v-18-6a-so8/dp/2056686?ost=2056686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) | here (http://www.farnell.com/datasheets/2050350.pdf?_ga=1.174217890.181503411.1480456472) | SOIC8_V1 | X | 5.99
16 | 1 | R1 | 2k2 | SMD Chip Resistor, Thick Film, 2.2 kohm, 150 V, 0805 | MULTICOMP | 9332812 | farnell | here (http://ro.farnell.com/multicomp/mc01w080512k2/res-thick-film-2k2-1-0-1w-0805/dp/9332812?ost=9332812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) | here (http://www.farnell.com/datasheets/1729047.pdf?_ga=1.204093200.181503411.1480456472) | SMR0805_V2 | X | 0.01
17 | 1 | R4 | 620 | SMD Chip Resistor, Thick Film, 620 ohm, 150 V, 0805 | MULTICOMP | 2447700 | farnell | here (http://ro.farnell.com/multicomp/mcwr08x6200ftl/res-thick-film-620-ohm-1-0-125w/dp/2447700?ost=2447700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) | here (http://www.farnell.com/datasheets/1849611.pdf?_ga=1.198276783.181503411.1480456472) | SMR0805_V2 | X | 0.03
18 | 2 | R5,R7 | 62 | SMD Chip Resistor, Ceramic, 62 ohm, 150 V, 0805 | MULTICOMP | 2073819 | farnell | here (http://ro.farnell.com/multicomp/mcmr08x62r0ftl/res-ceramic-62r-1-0-125w-0805/dp/2073819?ost=2073819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) | here (http://www.farnell.com/datasheets/1716708.pdf?_ga=1.241898370.181503411.1480456472) | SMR0805_V2 | X | 0.13
19 | 3 | R2,R6,R10 | 1k | SMD Chip Resistor, Thick Film, 1 kohm, 150 V, 0805 | MULTICOMP | 9332383 | farnell | here (http://ro.farnell.com/multicomp/mc01w080511k/res-thick-film-1k-1-0-1w-0805/dp/9332383?ost=9332383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) | here (http://www.farnell.com/datasheets/1729047.pdf?_ga=1.164896447.181503411.1480456472) | SMR0805_V2 | X | 0.1
20 | 1 | R3 | 0.68 | SMD Chip Resistor, Thick Film, 0.68 ohm, 0805 [2012 Metric], 125 mW, ± 1% | YAGEO | 1779443 | farnell | here (http://ro.farnell.com/yageo-phycomp/rl0805fr-070r68l/res-thick-film-0r68-1-0-125w-0805/dp/1779443?ost=1779443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) | here (http://www.farnell.com/datasheets/2167177.pdf?_ga=1.240800515.181503411.1480456472) | SMR0805_V2 | X | 1.12
21 | 1 | R8 | 12k1 | SMD Chip Resistor, Thick Film, 12.1 kohm, 150 V, 0805 | MULTICOMP | 2141849 | farnell | here (http://ro.farnell.com/multicomp/mc01w0805112k1/res-thick-film-12k1-1-0-1w-0805/dp/2141849?ost=2141849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) | here (http://www.farnell.com/datasheets/1729047.pdf?_ga=1.262689292.181503411.1480456472) | SMR0805_V2 | X | 0.01
22 | 1 | R11 | 220k | SMD Chip Resistor, Ceramic, 220 kohm, 150 V, 0805 | MULTICOMP | 2074407 | farnell | here (http://ro.farnell.com/multicomp/mcsr08x2203ftl/res-ceramic-220k-1-0-125w-0805/dp/2074407?ost=2074407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) | here (http://www.farnell.com/datasheets/1716717.pdf?_ga=1.202964881.181503411.1480456472) | SMR0805_V2 | X | 0.16
23 | 1 | R9 | 0.025 | Resistor: thick film; sensing; SMD; 0805; 25mΩ; 0.125W; ±1% | VIKING | CS05FTJWR025 | TME | here (http://www.tme.eu/en/details/cs0805-0r025-1%25/0805-smd-resistors/viking/cs05ftjwr025/) | here (http://www.tme.eu/en/Document/a812535aec0aa18fd47b9a8fc0cc2be6/CS%20REV.D3-160715.pdf) | SMR0805_V2 | X | 0.86
24 | 2 | R12,R13 | 3k3 | SMD Chip Resistor, Thick Film, 3.3 kohm, 150 V, 0805 | MULTICOMP | 9334360 | farnell | here (http://ro.farnell.com/multicomp/mc01w080553k3/res-thick-film-3k3-5-0-1w-0805/dp/9334360?ost=9334360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) | here (http://www.farnell.com/datasheets/1716700.pdf?_ga=1.6887090.181503411.1480456472) | SMR0805_V2 | X | 0.07
25 | 2 | VREG1,VREG3 | AMSR2-7805-NZ | Converter: DC/DC; 10W; Uin:7÷18V; Uout:5VDC; Iout:2A | AIMTEC | AMSR2-7805-NZ | TME | here (http://www.tme.eu/en/details/amsr2-7805-nz/dcdc-converters/aimtec/) | here (http://www.tme.eu/en/Document/556572662bf612a19ddd33a8ca460f37/AMSR2-78-NZ.pdf) | AMSR2-7805-NZ_V0 | 1mm | 36.15
26 | 1 | VREG2 | MIC29302WU | LDO Voltage Regulator, Adjustable, 2V to 26V input, 370 mV drop.,TO-263-5 | MICROCHIP | 2510026 | farnell | here (http://ro.farnell.com/microchip/mic29302wu/v-reg-ldo-3a-adj-29302-to-263/dp/2510026?ost=2510026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) | here (http://www.farnell.com/datasheets/94451.pdf?_ga=1.206599955.181503411.1480456472) | TO_236_5LEAD | X | 10.62
27 | 1 | U1 | BQ2057WSN | Battery Charger for 2 Cells of Li-Ion, Li-Pol battery, 15V input, 8.4V / 2A charge, SOIC-8 | TI | 1212263 | farnell | here (http://ro.farnell.com/texas-instruments/bq2057wsn/ic-charge-manager-li-ion-soic/dp/1212263?ost=1212263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) | here (http://www.ti.com/general/docs/lit/getliterature.tsp?genericPartNumber=BQ2057W&&fileType=pdf) | SOIC8_V1 | X | 13.54
28 | 1 | U2 | LTC4150 | Li-Ion, NiCd, NiMH Battery Fuel Gauge IC, 2.7 V to 8.5 V supply, - interface, MSOP-10 | LT | 1648053 | farnell | here (http://ro.farnell.com/linear-technology/ltc4150cms-pbf/batt-gas-gauge-coul-counter-10msop/dp/1648053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) | here (http://www.farnell.com/datasheets/1712269.pdf?_ga=1.164757311.181503411.1480456472) | MSOP10_V1 | X | 17.05
PCB Components (Command&Control Module PCB)
Nr. Crt | Quantity | Reference | Part | Description | Producer | Order Code | Supplier | Order Page | Datasheet | Footprint | Drill | Price (RON)
1 | 1 | J1 | CON5 | Socket; wire-board; male; PIN:5; 2.54mm; THT; KK 254; 4A | MOLEX | MX-6410-05A | TME | here (http://www.tme.eu/en/details/mx-6410-05a/raster-signal-connectors-254mm/molex/022272051-22-27-2051-ae-6410-05a102/) | here (http://www.tme.eu/en/Document/21768b6933f7cc0201d962c7c9c8c293/mx6410.pdf) | MOLEX5 | 1mm | 0.85
2 | 1 | J2 | CON2 | Socket; wire-board; male; PIN:2; 2.54mm; THT; KK 254; 4A | MOLEX | MX-6410-02A | TME | here (http://www.tme.eu/en/details/mx-6410-02a/raster-signal-connectors-254mm/molex/022272021-22-27-2021-ae-6410-02a102/) | here (http://www.tme.eu/en/Document/21768b6933f7cc0201d962c7c9c8c293/mx6410.pdf) | MOLEX2 | 1mm | 0.49
3 | 1 | D1 | LED | MULTICOMP 703-0097 LED, Green, Through Hole, 5mm, 20 mA, 2.1 V, 572 nm | multicomp | 2112108 | farnell | here (http://ro.farnell.com/multicomp/703-0097/led-5mm-green-150mcd-572nm/dp/2112108) | here (http://www.farnell.com/datasheets/1626763.pdf?_ga=1.6378418.181503411.1480456472) | CAPPR250-450x750N | 1mm | 1.22
4 | 1 | D2 | LED | MULTICOMP 703-0099 LED, Orange, Through Hole, 5mm, 20 mA, 2.1 V, 629 nm | multicomp | 2112110 | farnell | here (http://ro.farnell.com/multicomp/703-0099/led-orange-5mm-standard/dp/2112110) | here (http://www.farnell.com/datasheets/1626764.pdf?_ga=1.161618748.181503411.1480456472) | CAPPR250-450x750N | 1mm | 1.22
5 | 1 | D3 | LED | CREE C566C-AFN-CV0W0342 LED, OVAL, 5MM, AMBER, 2.5CD, 591NM | CREE | 2414446 | farnell | here (http://ro.farnell.com/cree/c566c-afn-cv0w0342/led-oval-5mm-amber-2-5cd-591nm/dp/2414446) | here (http://www.farnell.com/datasheets/2047792.pdf?_ga=1.240783875.181503411.1480456472) | CAPPR250-450x750N | 1mm | 1.22
6 | 1 | D4 | LED | LED, Red, Through Hole, 5mm, 20 mA, 2.1 V, 626 nm | Broadcom | 2497377 | farnell | here (http://ro.farnell.com/broadcom-limited/hlmp-hg74-xy0dd/led-5mm-red-2-4cd-626nm/dp/2497377) | here (http://www.farnell.com/datasheets/1932957.pdf?_ga=1.166360894.181503411.1480456472) | CAPPR250-450x750N | 1mm | 3.32
7 | 1 | SW1 | SWITCH | Microswitch, 1-position, SPST-NO, 0.05A/24VDC, THT, 1.47N, 6x6mm | OMRON | B3F-1052 | TME | here (http://www.tme.eu/en/details/b3f-1052/microswitches-tact-pcb/omron/) | here (http://www.tme.eu/en/Document/5082f4693da3491a7e9c22fc5e71c926/B3Fx105x4000.pdf) | SW320 | 1mm | 0.87
Extras (female connectors, contacts, battery)
Nr. Crt | Quantity | Reference | Part | Description | Producer | Order Code | Supplier | Order Page | Datasheet | Footprint | Drill | Price (RON)
1 | 1 | X | SWITCH | ROCKER; 2-position; SPST; OFF-ON; 10A/250VAC; black; Body: black | BULGIN | AE-H8800VAAAA | TME | here (http://www.tme.eu/en/details/ae-h8800vaaaa/rocker-switches/bulgin/h8800vabb/) | here (http://www.tme.eu/en/Document/19e16a93f9257750793bb0d9f4f9420f/Rocker%208800_series-DTE.pdf) | X | X | 6.72
2 | 8 | X | SPACER | Screwed spacer sleeve; Int.thread: M3; 5mm; Ext.thread: UNC4-40 | DREMEC | TFM-5/4/DR2130 | TME | here (http://www.tme.eu/en/details/tfm-5_4_dr2130/metal-spacers/dremec/2130x054/) | here (http://www.tme.eu/en/Document/3ac1ef7297f6f00e75f188402dc5d7f6/DR2103.pdf) | X | X | 0.56
3 | 4 | X | CON10 | Plug; IDC; female; PIN:10; IDC; for ribbon cable; 1.27mm | TE CONECTIVITY | 1658621-1 | TME | here (http://www.tme.eu/en/details/1658621-1/idc-connectors/te-connectivity/) | here (http://www.tme.eu/en/Document/0dd1db92d99ce5cbb2c6e4ec15e9c112/1658621-1.pdf) | X | X | 4.20
4 | 2 | X | CON5 | Plug; wire-board; female; PIN:5; w/o terminals; 2.54mm; for cable | MOLEX | MX-2695-05RP | TME | here (http://www.tme.eu/en/details/mx-2695-05rp/raster-signal-connectors-254mm/molex/022013057-22-01-3057-2695-05rp/) | here (http://www.tme.eu/en/Document/ee78bf13e4a5bc33097d02a34868528c/022013057.pdf) | X | X | 0.51
5 | 4 | X | CON2 | Plug; wire-board; female; PIN:2; w/o terminals; 2.54mm; for cable | MOLEX | MX-22-01-3037 | TME | here (http://www.tme.eu/en/details/mx-6471-021/raster-signal-connectors-254mm/molex/022012025-22-01-2025-6471-02i/) | here (http://www.tme.eu/en/Document/7bcd7a41035ae8e4e34efd9ce6ad8d35/mx2695.pdf) | X | X | 0.26
6 | 20 | X | pins | Contact; female; 30÷22AWG; KK 254; gold plated; crimped; bulk | MOLEX | MX-08-55-0102 | TME | here (http://www.tme.eu/en/details/mx-08-55-0102/raster-signal-connectors-254mm/molex/008550102-2759-555l/) | here (http://www.tme.eu/en/Document/97457d916bbfadc41b997225fed95ec6/MX-08-55-0102.pdf) | X | X | 0.27
7 | 1 | X | ribbon cable | Ribbon Cable, Colour Coded Flat, Per M, Multi-coloured, 9 Core, 28 AWG, 0.072 mm² | 3M | 1207415 | farnell | here (http://ro.farnell.com/3m/3302-9/ribbon-cable-9way-per-m/dp/1207415) | here (http://www.farnell.com/datasheets/22779.pdf?_ga=1.241317762.181503411.1480456472) | X | X | 11.47
8 | 1 | X | TH1 | Thermistor, NTC, 10 kohm, NTCLE Series, 3977 K, Through Hole, Radial Leaded | VISHAY | 1187031 | farnell | here (http://ro.farnell.com/vishay/ntcle100e3103jb0/thermistor-10k-5-ntc-rad/dp/1187031?ost=1187031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) | here (http://www.farnell.com/datasheets/2046167.pdf?_ga=1.170620576.181503411.1480456472) | X | X | 2.59
8 | 2 | X | BT1 | Re-battery: Li-Po; 3.7V; 2000mAh; Leads: cables; 7.3x30.5x86.5mm | CELLEVIA | ACCU-LP683086/CL | TME | here (http://www.tme.eu/ro/details/accu-lp683086_cl/acumulatori/cellevia-batteries/lp683086/) | here (http://www.tme.eu/ro/Document/09a69cb127ef0988d476edb000187cb0/ACCU-LP683086.pdf) | X | X | 49.14
 |  |  |  |  |  |  |  |  |  |  |  | TOTAL (RON)
 |  |  |  |  |  |  |  |  |  |  |  | 342.26

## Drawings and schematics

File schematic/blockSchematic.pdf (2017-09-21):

POWER MODULE | RPi 2 MODULE

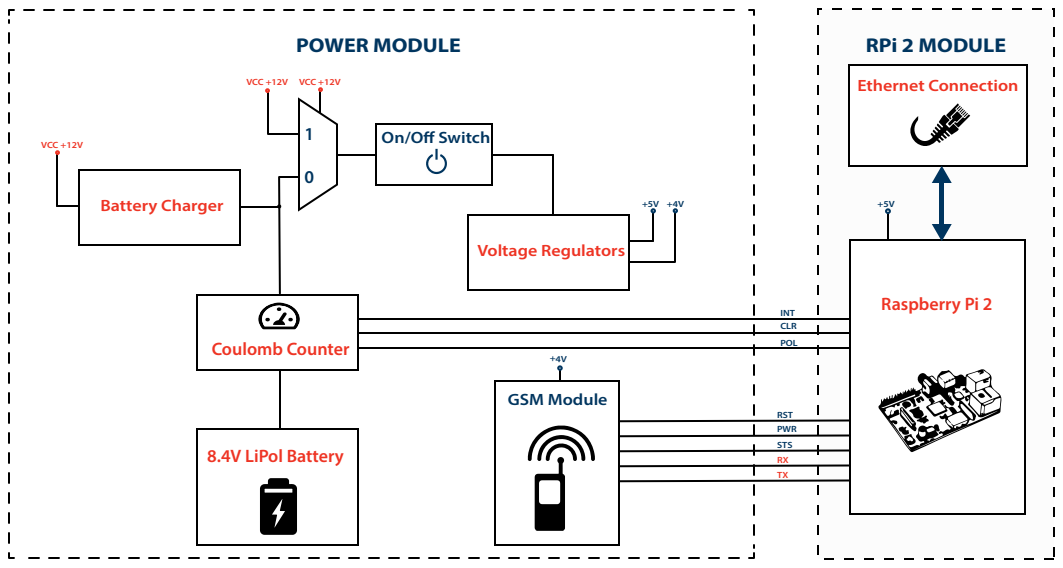
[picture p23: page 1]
Battery Charger; Coulomb Counter; 8.4V LiPol Battery; On/O Switch; GSM Module; Voltage Regulators; VCC +12V; VCC +12V VCC +12V; Raspberry Pi 2; Ethernet Connection; INT CLR POL; RST PWR STS RX TX

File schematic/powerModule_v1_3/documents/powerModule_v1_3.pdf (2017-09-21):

## 3 Small Signal Diodes for a drop or aprox 3*0.6V at a

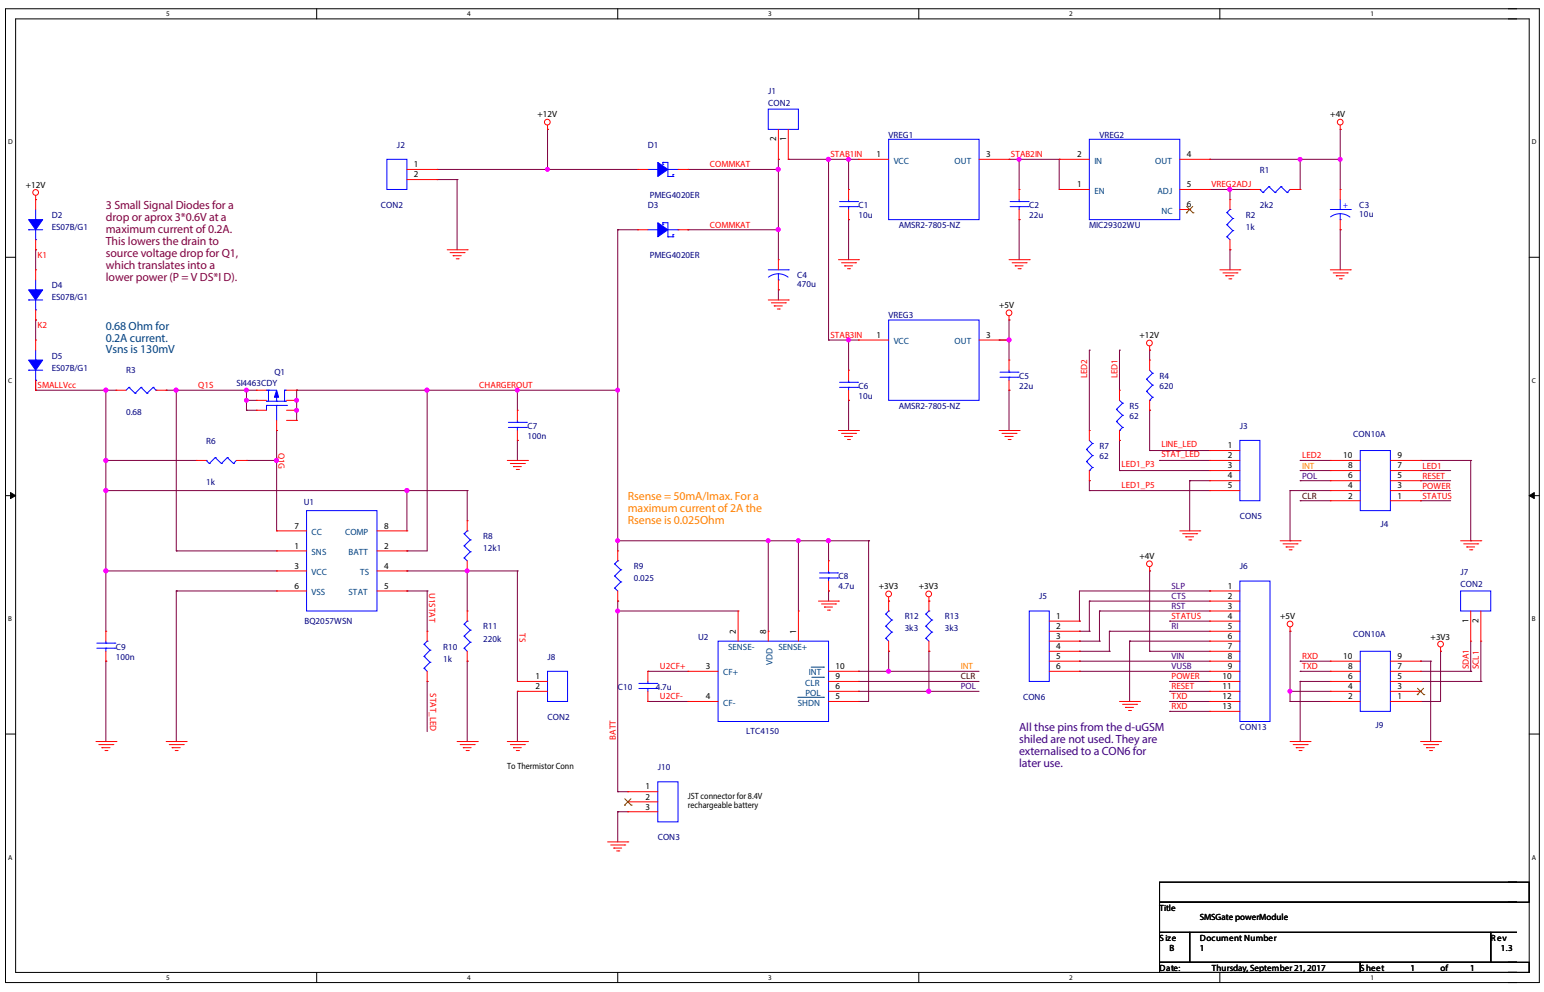
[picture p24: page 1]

maximum current of 0.2A.
This lowers the drain to
source voltage drop for Q1,
which translates into a
lower power (P = V DS*I D).

0.68 Ohm for 0.2A current. Vsns is 130mV

Rsense = 50mA/Imax. For a
maximum current of 2A the
Rsense is 0.025Ohm

All thse pins from the d-uGSM
shiled are not used. They are
externalised to a CON6 for later use.

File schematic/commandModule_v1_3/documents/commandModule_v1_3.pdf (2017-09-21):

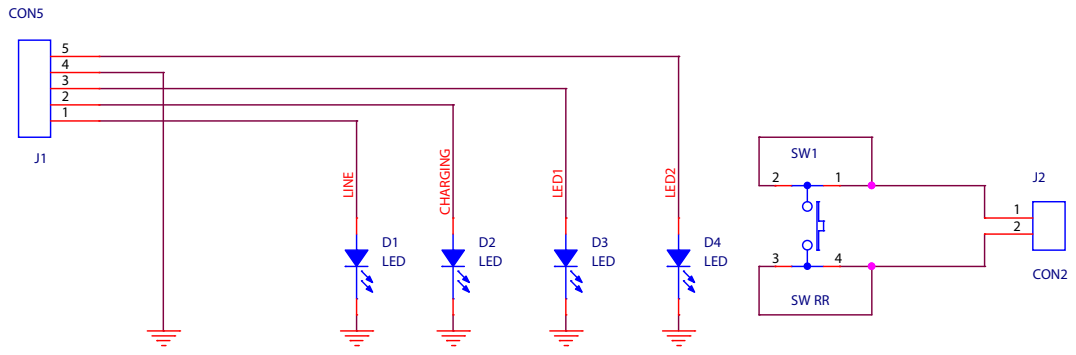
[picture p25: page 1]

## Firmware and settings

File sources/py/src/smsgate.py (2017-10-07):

############################################################################################################################################
# COPYRIGHT (C) 2016 Razvan Petre
# * Licensed under the Apache License, Version 2.0 (the "License");
# * you may not use this file except in compliance with the License.
# * You may obtain a copy of the License at
# *
# * http://www.apache.org/licenses/LICENSE-2.0
# *
# * Unless required by applicable law or agreed to in writing, software
# * distributed under the License is distributed on an "AS IS" BASIS,
# * WITHOUT WARRANTIES OR CONDITIONS OF ANY KIND, either express or implied.
# * See the License for the specific language governing permissions and
# * limitations under the License.

# This library is based on code developed by Dragos Iosub, Bucharest 2015. http://itbrainpower.net,original code link below:
# http://itbrainpower.net/micro-GSM-shield-module-cuGSM/GSM-micro-shield-board-module-RaspberryPI-Arduino-c-uGSM-features-code-examples
#
# NAME: smsgate.py
# PROJECT: SMSGate
# DESCRIPTION: This module has the main function of the whole application

############################################################################################################################################

# !/usr/bin/python
from Daemon import *


if __name__ == "__main__":
    if len(sys.argv) == 2:
        if 'start' == sys.argv[1]:
            if daemon.getPID():
                print 'smsgate daemon is already running!Use stop before start'
                sys.exit(1)
            else:
                daemon.start()
        elif 'stop' == sys.argv[1]:
            if not daemon.getPID():
                print 'NO smsgate daemon is running!Use start before stop'
                sys.exit(1)
            else:
                daemon.stop()
        elif 'status' == sys.argv[1]:
            if not daemon.getPID():
                print 'NO smsgate daemon is running!Use start before status'
                sys.exit(1)
            else:
                os.kill(daemon.getPID(), signal.SIGUSR1)
                time.sleep(10)

        elif 'help' == sys.argv[1]:
            print "usage: %s start|stop|restart|status|help" % sys.argv[0]
        else:
            print "Unknown command. See help for more info"
            sys.exit(2)
        sys.exit(0)
    else:
        print "usage: %s start|stop|restart|status|help" % sys.argv[0]
        sys.exit(2)

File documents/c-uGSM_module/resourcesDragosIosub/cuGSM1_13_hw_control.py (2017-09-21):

############################################################################################################################################
#cuGSM1_13_hw_control.py v1.01/08September2015 - c-uGSM 1.13 rev 1 HARDWARE CONTROL library 
#COPYRIGHT (c) 2015 Dragos Iosub / R&D Software Solutions srl
#
#You are legaly entitled to use this SOFTWARE ONLY IN CONJUNCTION WITH c-uGSM DEVICES USAGE. Modifications, derivates and redistribution 
#of this software must include unmodified this COPYRIGHT NOTICE. You can redistribute this SOFTWARE and/or modify it under the terms 
#of this COPYRIGHT NOTICE. Any other usage may be permited only after written notice of Dragos Iosub / R&D Software Solutions srl.
#
#This SOFTWARE is distributed is provide "AS IS" in the hope that it will be useful, but WITHOUT ANY WARRANTY; without even the implied 
#warranty of MERCHANTABILITY or FITNESS FOR A PARTICULAR PURPOSE.
#
#Dragos Iosub, Bucharest 2015.
#http://itbrainpower.net
############################################################################################################################################
import os
import RPi.GPIO as GPIO
from globalParVar import *
from time import sleep
from cuGSM_Serial_Lib import *

# getModemState()
# returns 1 if the modem is up, 0 else
def getModemState():
        return GPIO.input(STATUS)

# getModemStateByAT()
# returns 1 if the modem is running, 0 else
# can be used as substitute for getModemState()
def getModemStateByAT():
        aGsmWRITE("+++\r\n")
        aGsmWRITE(chr(0x1B)+"\r\n")
        aGsmWRITE("AT\r\n")
        aGsmWRITE("ATE1\r\n")
        aGsmWRITE("ATV1\r\n")
        clearSInput()
        clearInput()
        res = sendATcommand("AT",["OK","ERROR"],1)
        if(res>0):
                return 1
        else:
                return 0

def poweron():
	#if not GPIO.input(STATUS):
	if not(getModemState()):
		print ("try to wake c-uGSM")
		#GPIO.output(POWER,GPIO.HIGH)
		#sleep(1)
		#GPIO.output(POWER,GPIO.LOW)
		GPIO.output(POWER,GPIO.LOW)
		sleep(1)
		GPIO.output(POWER,GPIO.HIGH)
	sleep(5)	
	#if GPIO.input(STATUS):
	if (getModemState()):
		print("c-uGSM is up")
	else:
		print("failure powering c-uGSM")
		exit(100)
	
def poweroff():
	#if GPIO.input(STATUS):
	if (getModemState()):
		print ("try to shutdown c-uGSM")
		#GPIO.output(POWER,GPIO.HIGH)
		#sleep(1)
		#GPIO.output(POWER,GPIO.LOW)
		GPIO.output(POWER,GPIO.LOW)
		sleep(1)
		GPIO.output(POWER,GPIO.HIGH)
	sleep(8)
	#if not GPIO.input(STATUS):
	if not(getModemState()):
		print("c-uGSM is down")
	else:
		print("failure powering off c-uGSM")
		exit(100)

def restartModem():
    poweroff()
    sleep(3)
    poweron()

def resetModem():
	print ("try to reset c-uGSM")
	#GPIO.output(RESET,GPIO.HIGH)
	#sleep(1)
	#GPIO.output(RESET,GPIO.LOW)
	GPIO.output(RESET,GPIO.LOW)
	sleep(1)
	GPIO.output(RESET,GPIO.HIGH)
	sleep(8)
	#if not GPIO.input(STATUS):
	if not(getModemState()):
		print("c-uGSM is down")
	else:
		print("failure reset c-uGSM")
		exit(100)

def hwControlSetup():
    GPIO.setmode(GPIO.BOARD)
    GPIO.setwarnings(False)
    try:
        GPIO.setup(STATUS, GPIO.IN)
        #GPIO.setup(POWER, GPIO.OUT, initial=GPIO.LOW)
        #GPIO.setup(RESET, GPIO.OUT, initial=GPIO.LOW)
        GPIO.setup(POWER, GPIO.OUT, initial=GPIO.HIGH)
        GPIO.setup(RESET, GPIO.OUT, initial=GPIO.HIGH)
    except:
        GPIO.cleanup()#free GPIO
        GPIO.setup(STATUS, GPIO.IN)
        #GPIO.setup(POWER, GPIO.OUT, initial=GPIO.LOW)
        #GPIO.setup(RESET, GPIO.OUT, initial=GPIO.LOW)
        GPIO.setup(POWER, GPIO.OUT, initial=GPIO.HIGH)
        GPIO.setup(RESET, GPIO.OUT, initial=GPIO.HIGH)
    GPIO.setwarnings(True)
    
def hwControlRelease():
    GPIO.cleanup()#free GPIO
